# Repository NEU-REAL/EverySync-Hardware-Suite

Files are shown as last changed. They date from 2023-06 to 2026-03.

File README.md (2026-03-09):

# EverySync --  An Open Hardware Time Syncronization Sensor Suite
**EverySync** is An Open Hardware Time Syncronization Sensor Suite For Every Casual Sensor In Field Of SLAM.
- Our project provides a complete, open-source hardware, firmware and software bundle to perform `Hardware Time Synchronization ` of multiple sensors in SLAM system.
  
<div align=center>
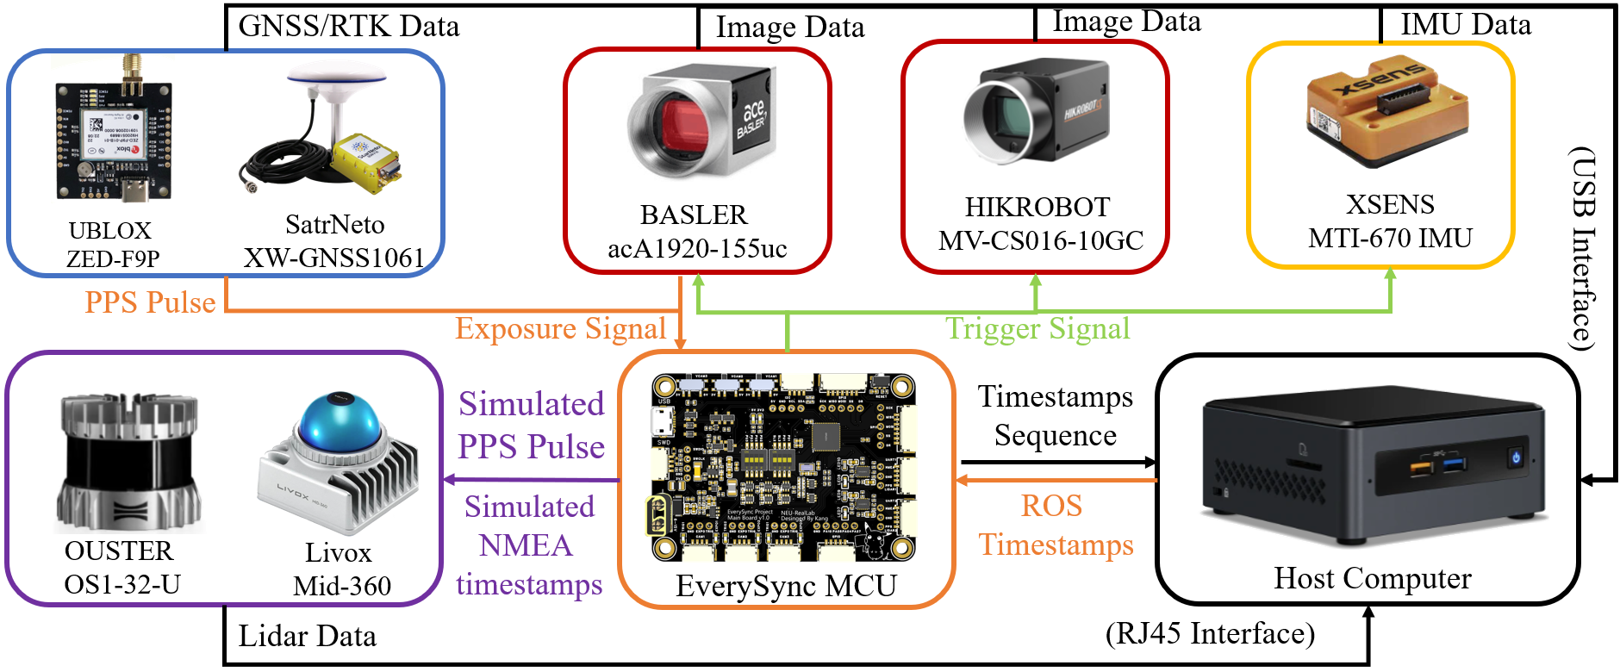
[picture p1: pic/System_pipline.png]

</div>

Entry of This Project:

* [EverySync -- HardwareSuite](https://github.com/NEU-REAL/EverySync-Hardware-Suite) Open source Hardware Suite of EverySync.
* [EverySync -- PCB and Examples](https://github.com/NEU-REAL/EverySync-Hardware-Suite/tree/master/EverySync_PCB) Released. Both [Altium Designer](https://github.com/NEU-REAL/EverySync-Hardware-Suite/tree/master/EverySync_PCB/PCB/EverySync_AD) and [LCEDA](https://oshwhub.com/theconquerk/01-mcu-schdoc_copy) versions are provided, make sure the project is easy to reproduce. And we also provide some examples for developers to create their own hardware suites.

<div align=center>
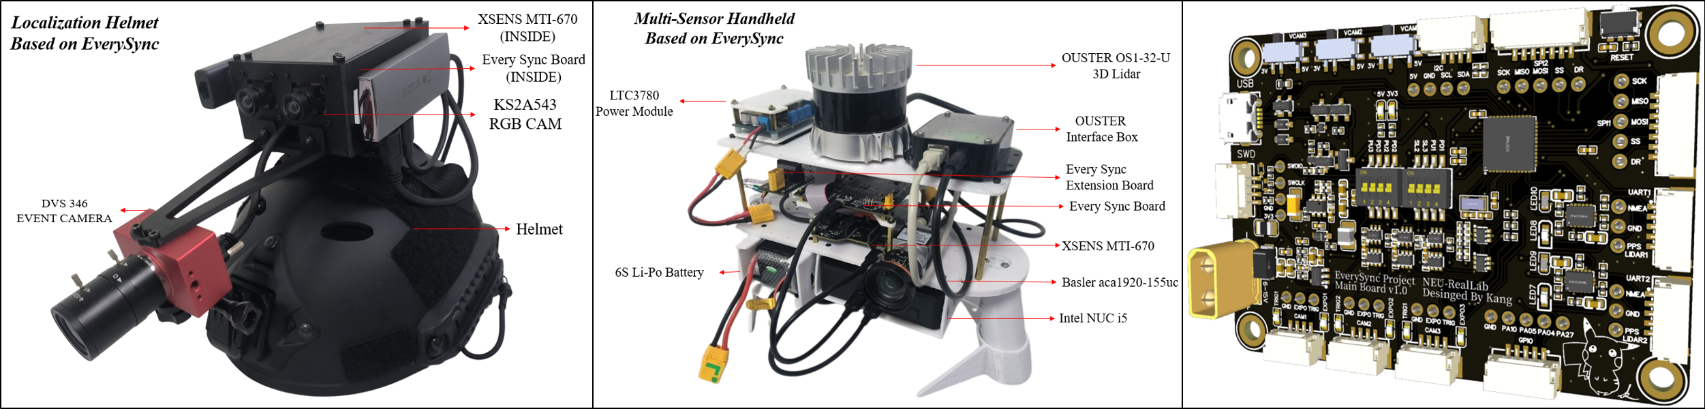
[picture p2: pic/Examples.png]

</div>

## News
- **May 26, 2022** Finish first version named RealVIS v1.0 .
- **May  8, 2023** Support at least 3 kinds of Lidar.
- **April  2, 2024** Open-source. Submit to IROS2024. Preprint is comming soon.
- **June  30, 2024** Accepted by IROS2024. 
- **December 26, 2024** Proceding of IROS2024 is released.
- **January  13, 2025** Project is totally open source. ⭐Happy New Year⭐. 

## Supported drivers
### Camera 
* [Basler](https://github.com/NEU-REAL/EverySync-Hardware-Suite/tree/master/src/driver/pylon-ros-camera) tested with acA1920-155uc
* [HikVision](https://github.com/NEU-REAL/EverySync-Hardware-Suite/tree/master/src/driver/HIKROBOT-MVS-CAMERA-ROS) tested with HikVision MV-CA023-10UC
#### Camera Support From VersaVIS
* [MatrixVision](https://github.com/ethz-asl/bluefox2/tree/devel/versavis) tested with Bluefox 2 MLC200WG, needs adaption for new format
* [PointGrey/Flir](https://github.com/ethz-asl/flir_camera_driver/tree/devel/versavis) tested with Chameleon 3, Blackfly S
* [CamBoard](https://github.com/ethz-asl/pico_flexx_driver/tree/devel/versavis) tested with CamBoard pico monstar

### TriggeralbeIMU
* [Xsens](https://github.com/NEU-REAL/EverySync-Hardware-Suite/tree/master/src/driver/xsens_ros) Support Xsens MTi-100 Series & Xsens MTi-600 Series.Tested with Xsens MTi-300,MTi-630,MTi-670-DK.

### IMU Support From VersaVIS
* [ADIS](https://github.com/NEU-REAL/EverySync-Hardware-Suite/tree/master/src/every_sync/every_sync/src) Originally Support ADIS16448 from VersaVIS

### Lidar
* [Ouster](https://github.com/NEU-REAL/EverySync-Hardware-Suite/tree/master/src/driver/pylon-ros-camera) tested with Ouster-OS1-32
* [Robosense](https://github.com/NEU-REAL/EverySync-Hardware-Suite/tree/master/src/driver/HIKROBOT-MVS-CAMERA-ROS) tested with Robosense16
* [Livox](https://github.com/NEU-REAL/EverySync-Hardware-Suite/tree/master/src/driver/HIKROBOT-MVS-CAMERA-ROS) tested with Livox Mid-40 , Mid-70 , Mid-360

### GNSS/GPS
* [Ublox](https://github.com/NEU-REAL/EverySync-Hardware-Suite/tree/master/src/driver/ublox_driver) tested with Ublox ZED-F9P

## Citing

```
@inproceedings{wu2024everysync,
  title={EverySync: An Open Hardware Time Synchronization Sensor Suite for Common Sensors in SLAM},
  author={Wu, Xuankang and Sun, Haoxiang and Wu, Rongguang and Fang, Zheng},
  booktitle={2024 IEEE/RSJ International Conference on Intelligent Robots and Systems (IROS)},
  pages={12587--12593},
  year={2024},
  organization={IEEE}
}
```

## Install

### Clone and build
```
cd catkin_ws/src
git clone https://github.com/NEU-REAL/EverySync-Hardware-Suite.git
catkin_make
```

```
cd everysync/firmware
./setup.sh
```

### Setup udev rule
Add yourself to `dialout` group
```
sudo adduser <username> dialout
```

Copy udev rule file to your system:
```
sudo cp firmware/98-versa-vis.rules /etc/udev/rules.d/98-versa-vis.rules
```
Afterwards, use the following commands to reload the rules
```
sudo udevadm control --reload-rules
sudo udevadm trigger
sudo ldconfig
```
Note: You might have to reboot your computer for this to take effect. You can check by see whether a `/dev/versavis` is available and pointing to the correct device.

### Configure
Adapt the [configuration file](https://github.com/ethz-asl/versavis/blob/master/firmware/libraries/versavis/src/versavis_configuration.h) to your setup needs. Also check the [datasheet](https://drive.google.com/file/d/11QCjc5PVuMU9bAr8Kjvqz2pqVIhoMbHA/view?ts=5dc98776) for how to configure the hardware switches.

### Flash firmware on the VersaVIS board
* Install the arduino IDE from [here](https://www.arduino.cc/en/Main/OldSoftwareReleases#previous). Use version 1.8.2!
    - Note that a small modification of the install script (`install.sh`) might be required. In particular you may need to change the line `RESOURCE_NAME=cc.arduino.arduinoide` to `RESOURCE_NAME=arduino-arduinoide` as per the issue [here](https://github.com/arduino/Arduino/issues/6116#issuecomment-290012812).
* Open `firmware/everysync/everysync.ino` in the IDE
* Go to `File -> Preferences`
* Change Sketchbook location to `versavis/firmware/`
* Install board support:
    - For EverySync: [Check here](https://github.com/ethz-asl/versavis_hw/)
* Set `Tools -> Port -> tty/ACM0 (Arduino Zero)`, and `Tools -> Board -> VersaVIS`.
* Compile using the *Verify* menu option
* Flash using the *Upload* menu option

## Usage
* Adapt `everysync/launch/pps_test.launch` to your needs.
* Run with
```
roslaunch everysync pps_test.launch
```
* Wait for successfull initialization.
* Or initialization by publish rostopic.
```
./init_cam.sh
```

## Acknowledgements
**There are several important works which support this project:**
- [VersaVIS](https://github.com/ethz-asl/versavis): An Open Versatile Multi-Camera Visual-Inertial Sensor Suite
- [Versavis-Hw](https://github.com/ethz-asl/versavis_hw): VersaVIS Board package for arduino IDE.

## Licence
The source code is released under [GPLv3](https://www.gnu.org/licenses/) license.

## Maintenance
We are still working on extending the proposed system and improving code reliability.

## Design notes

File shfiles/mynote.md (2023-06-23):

->启动 
setserial /dev/ttyUSB0 low_latency
roslaunch versavis real_start.launch
->rosserial单独连接触发板 
->rostopic复位触发板 
$ rosrun rosserial_arduino serial_node.py _port:=/dev/versavis _baud:=250000
$ rostopic pub /versavis/reset std_msgs/Bool false --once

Attention:初次上电后需要复位触发板 复位后立即启动real_start.launch
->python 录制数据包
$ rosbag record -O ms_test.bag  /versavis/cam1/image_raw /versavis/cam2/image_raw /versavis/cam1/image_time /versavis/cam2/image_time /versavis/xsens_imu/image_time /versavis/xsens_imu/data

->python 画图评估脚本

-->ros到达时间给定时间戳计算
$ python real_show_timings.py --input_rosbag /home/kang/realvisWs/bag_file/ms_test.bag --topic /versavis/cam2/image_time

-->延迟时间计算：此延迟是积分时间结束与 ROS 驱动程序给出的时间戳之间的时间。 通常，这对应于传感器的最高帧速率（也可能受接口带宽的影响）。
$ python real_calculate_img_delay.py --input_rosbag /home/kang/realvisWs/bag_file/ms_test.bag --cam0 /versavis/cam1/image_raw --cam1 /versavis/cam2/image_raw
->录制轨迹地图数据包
rosbag record -O realvis_track_5_25_1.bag /versavis/xsens_imu/data /versavis/cam1/image_raw /hikrobot_camera/rgb /imu/data /mynteye/left_rect/image_rect /mynteye/imu/data_raw

截取		
		secs:  1653313555
		nsecs:  1081023

		secs:  1653313759
		nsecs:  751216031

rosbag filter realvis_track_5_23_0.bag cut_realvis_track.bag "t.to_sec() >= 1653313555.1081023 and t.to_sec() <= 1653313759.751216031"

rosbag record -O mynt_track.bag /mynteye/left_rect/image_rect /mynteye/imu/data_raw

rosbag record -O orb_track_5_25_1.bag /versavis/xsens_imu/data /versavis/cam1/image_raw /hikrobot_camera/rgb /imu/data /mynteye/left_rect/image_rect /mynteye/imu/data_raw

#轨迹绘制
1. 数据转换
evo_traj euroc data.csv --save_as_tum
2. 轨迹绘制
evo_traj tum vins_result_no_loop.csv -p --plot_mode=xy
evo_traj tum vins_result_loop.csv -p --plot_mode=xy
evo_traj tum 5_25_1mynt/vins_result_no_loop.csv 5_25_1realvis_sync/vins_result_no_loop.csv -p --plot_mode=xy
evo_traj tum 5_25_1mynt/vins_result_no_loop.csv 5_25_1realvis_sync/vins_result_no_loop.csv -p --plot_mode=xy

xsens mti ros driver attention!!!
The published topics do not reach the expected data output rate (e.g. 400 Hz).
We have noticed that the ROS node can cause a high CPU load, leading to lower data output rates. This issue has been fixed in ROS nodes available in MTSS2019.3.2 and later. We recommend migrating to the latest version.

If you have connected the MTi via a USB interface, we recommend enabling the low latency mode using setserial:

Install setserial if not already installed
Enable low latency mode:

$ setserial [/path/to/xsens/port] low_latency
setserial /dev/ttyUSB0 low_latency

Check the output rate of the published topics, e.g:

$ rostopic hz imu/data

imu timestamp

		nsecs:  462945000
		nsecs:  472942000
		nsecs:  482940000
		nsecs:  492938000
均匀
bag1
image timestamp 1
		nsecs:  101840000
		nsecs:  149825000
		nsecs:  197811000

image timestamp 2
		nsecs:  149967000
		nsecs:  197953000
		nsecs:  245938000

		secs:  1682585875
		nsecs:  830734968
		secs:  303067339
		nsecs:  880780000

		secs:  1682586175
		nsecs:  451132059
		secs:  3358979009
		nsecs:  749697000

43.183
		secs:  1686309290
		nsecs:  448941000

		secs:  1686309290
		nsecs:  505958519

57,017,519

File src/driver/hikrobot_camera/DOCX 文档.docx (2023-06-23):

HIKROBOT_VISION

管脚 信号

I/O 信号源 说明

1

DC_PWR

相机电源

2

OPTO_IN

Line 0+

光耦隔离输入

3

GPIO

Line 2+

可配置输入或输出

4

OPTO_OUT

Line 1+

光耦隔离输出

5

OPTO_GND

Line 0/1-

光耦隔离信号地

6

GND

Line 2-

相机电源地

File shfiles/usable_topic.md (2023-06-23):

/REAL_camera_manager/bond
/basler_camera_node/img_numbered
/clicked_point
/diagnostics
/hikrobot_camera/camera_info
/hikrobot_camera/img_numbered
/hikrobot_camera/rgb
/hikrobot_camera/rgb/compressed
/hikrobot_camera/rgb/compressed/parameter_descriptions
/hikrobot_camera/rgb/compressed/parameter_updates
/hikrobot_camera/rgb/compressedDepth
/hikrobot_camera/rgb/compressedDepth/parameter_descriptions
/hikrobot_camera/rgb/compressedDepth/parameter_updates
/hikrobot_camera/rgb/theora
/hikrobot_camera/rgb/theora/parameter_descriptions
/hikrobot_camera/rgb/theora/parameter_updates
/imu/data
/imu_data_str
/initialpose
/move_base_simple/goal
/pylon_camera_node/camera_info
/pylon_camera_node/currentParams
/pylon_camera_node/grab_images_raw/cancel
/pylon_camera_node/grab_images_raw/feedback
/pylon_camera_node/grab_images_raw/goal
/pylon_camera_node/grab_images_raw/result
/pylon_camera_node/grab_images_raw/status
/pylon_camera_node/image_raw
/pylon_camera_node/image_raw/compressed
/pylon_camera_node/image_raw/compressed/parameter_descriptions
/pylon_camera_node/image_raw/compressed/parameter_updates
/pylon_camera_node/image_raw/compressedDepth
/pylon_camera_node/image_raw/compressedDepth/parameter_descriptions
/pylon_camera_node/image_raw/compressedDepth/parameter_updates
/pylon_camera_node/image_raw/theora
/pylon_camera_node/image_raw/theora/parameter_descriptions
/pylon_camera_node/image_raw/theora/parameter_updates
/pylon_camera_node/status
/rosout
/rosout_agg
/tf
/tf_static
/time_reference
/versavis/cam1/image_raw
/versavis/cam1/image_raw/compressed
/versavis/cam1/image_raw/compressed/parameter_descriptions
/versavis/cam1/image_raw/compressed/parameter_updates
/versavis/cam1/image_raw/compressedDepth
/versavis/cam1/image_raw/compressedDepth/parameter_descriptions
/versavis/cam1/image_raw/compressedDepth/parameter_updates
/versavis/cam1/image_raw/theora
/versavis/cam1/image_raw/theora/parameter_descriptions
/versavis/cam1/image_raw/theora/parameter_updates
/versavis/cam1/image_time
/versavis/cam1/init
/versavis/cam2/image_raw
/versavis/cam2/image_raw/compressed
/versavis/cam2/image_raw/compressed/parameter_descriptions
/versavis/cam2/image_raw/compressed/parameter_updates
/versavis/cam2/image_raw/compressedDepth
/versavis/cam2/image_raw/compressedDepth/parameter_descriptions
/versavis/cam2/image_raw/compressedDepth/parameter_updates
/versavis/cam2/image_raw/theora
/versavis/cam2/image_raw/theora/parameter_descriptions
/versavis/cam2/image_raw/theora/parameter_updates
/versavis/cam2/image_time
/versavis/cam2/init
/versavis/reset
/versavis/xsens_imu/data
/versavis/xsens_imu/image_time
/versavis/xsens_imu/init
/xsens/imu_numbered

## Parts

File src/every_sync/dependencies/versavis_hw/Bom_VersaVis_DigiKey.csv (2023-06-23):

Manufacturer Part Number | Manufacturer | Digi-Key Part Number | Reference Designator | Packaging | Part Status | Quantity | Unit Price | Extended Price | Quantity Available | Mfg Std Lead Time | Description
CRCW060350R0FKEA | Vishay Dale | 541-3318-1-ND | R102 | Cut Tape (CT) | Active | 1 | 0,09000 | 0,09 € | 0 | 52 Weeks | RES SMD 50 OHM 1% 1/10W 0603
C0603C472K1GEC7867 | KEMET | 399-14206-1-ND | C101, C201, C202 | Cut Tape (CT) | Active | 3 | 0,26000 | 0,78 € | 3719 | 24 Weeks | CAP CER 4700PF 100V C0G/NP0 0603
CL21B105KAFNNNE | Samsung Electro-Mechanics | 1276-1066-1-ND | C203, C204, C205 | Cut Tape (CT) | Active | 3 | 0,09000 | 0,27 € | 15526 | 28 Weeks | CAP CER 1UF 25V X7R 0805
C0603C104J4RACTU | KEMET | 399-1097-1-ND | C207, C401, C501, C601_1, C601_2, C601_3, C602_1, C602_2, C602_3, C603_1, C603_2, C603_3, C304, C305, C307, C309 | Cut Tape (CT) | Active | 16 | 0,08500 | 1,36 € | 1900438 | 23 Weeks | CAP CER 0.1UF 16V X7R 0603
04023A200JAT2A | AVX Corporation | 478-11740-1-ND | C301, C302 | Cut Tape (CT) | Active | 2 | 0,26000 | 0,52 € | 4922 | 16 Weeks | CAP CER 20PF 25V C0G/NP0 0402
GRM188C81C475KE11D | Murata Electronics | 490-13362-1-ND | C303, C306, C308 | Cut Tape (CT) | Active | 3 | 0,32000 | 0,96 € | 0 | 23 Weeks | CAP CER 4.7UF 16V X6S 0603
GRM21BC71E106KE11L | Murata Electronics | 490-10496-1-ND | C402, C403, C206 | Cut Tape (CT) | Active | 3 | 0,51000 | 1,53 € | 66009 | 23 Weeks | CAP CER 10UF 25V X7S 0805
0430450400 | Molex | WM1814-ND | CAM101, CAM102, CAM103 | Tray | Active | 3 | 1,20000 | 3,60 € | 26834 | 6 Weeks | CONN HEADER R/A 4POS 3MM
PRTR5V0U2X,215 | Nexperia USA Inc. | 1727-3884-1-ND | D101 | Cut Tape (CT) | Active | 1 | 0,41000 | 0,41 € | 531 | 8 Weeks | TVS DIODE 5.5V SOT143B
B0540W-7-F | Diodes Incorporated | B0540W-FDICT-ND | D102, D201, D203 | Cut Tape (CT) | Active | 3 | 0,27000 | 0,81 € | 0 | 24 Weeks | DIODE SCHOTTKY 40V 500MA SOD123
LG R971-KN-1 | OSRAM Opto Semiconductors Inc. | 475-1410-1-ND | D202, D204, D504, D505, D506 | Cut Tape (CT) | Active | 5 | 0,22000 | 1,10 € | 283121 | 12 Weeks | LED GREEN DIFFUSED 0805 SMD
LO R976-PS-1 | OSRAM Opto Semiconductors Inc. | 475-2488-2-ND | D501, D502, D503 | Tape & Reel (TR) | Active | 3 | 0,00000 | 0,00 € | 4307 | 16 Weeks | LED ORANGE DIFFUSED 0805 SMD
MF-MSMF050-2 | Bourns Inc. | MF-MSMF050-2CT-ND | F201, F202 | Cut Tape (CT) | Active | 2 | 0,27000 | 0,54 € | 11326 | 20 Weeks | PTC RESET FUSE 15V 500MA 1812
DF13A-4P-1.25H(51) | Hirose Electric Co Ltd | H125779CT-ND | I101 | Cut Tape (CT) | Active | 1 | 0,79000 | 0,79 € | 52 | 26 Weeks | CONN HEADER SMD R/A 4POS 1.25MM
0475890001 | Molex | WM17143CT-ND | J101 | Cut Tape (CT) | Active | 1 | 0,66000 | 0,66 € | 16302 | 12 Weeks | CONN RCPT MICRO USB AB 5P SMD RA
BLM18PG471SN1D | Murata Electronics | 490-5223-1-ND | L201 | Cut Tape (CT) | Active | 1 | 0,09000 | 0,09 € | 0 | 15 Weeks | FERRITE BEAD 470 OHM 0603 1LN
BLM21BD152SN1D | Murata Electronics | 490-1048-1-ND | L301 | Cut Tape (CT) | Active | 1 | 0,18000 | 0,18 € | 13310 | 16 Weeks | FERRITE BEAD 1.5 KOHM 0805 1LN
2N7002DW-7-F | Diodes Incorporated | 2N7002DW-FDICT-ND | Q201 | Cut Tape (CT) | Active | 1 | 0,30000 | 0,30 € | 0 | 45 Weeks | MOSFET 2N-CH 60V 0.23A SOT-363
ERJ-3GEYJ105V | Panasonic Electronic Components | P1.0MGCT-ND | R101 | Cut Tape (CT) | Active | 1 | 0,09000 | 0,09 € | 263582 | 29 Weeks | RES SMD 1M OHM 5% 1/10W 0603
RT0603FRE0710KL | Yageo | YAG2321CT-ND | R201, R205, R302, R303, R403, R404, R407, R408, R601_1, R601_2, R601_3, R602_1, R602_2, R602_3, R603_1, R603_2, R603_3 | Cut Tape (CT) | Active | 17 | 0,04800 | 0,81 € | 129389 | 20 Weeks | RES SMD 10K OHM 1% 1/10W 0603
CRCW0603270RFKEA | Vishay Dale | 541-270HCT-ND | R202, R405, R406, R501, R502, R503, R504, R505, R506 | Cut Tape (CT) | Active | 9 | 0,09000 | 0,81 € | 0 | 52 Weeks | RES SMD 270 OHM 1% 1/10W 0603
RT0603FRE07100KL | Yageo | YAG2319CT-ND | R203, R207, R208 | Cut Tape (CT) | Active | 3 | 0,09000 | 0,27 € | 84 | 20 Weeks | RES SMD 100K OHM 1% 1/10W 0603
CRCW0603470RFKEAC | Vishay Dale | 541-4038-1-ND | R204, R206, R304, R306 | Cut Tape (CT) | Active | 4 | 0,09000 | 0,36 € | 37544 | 22 Weeks | RES 470 OHM 1% 1/10W 0603
CPF0603B39RE1 | TE Connectivity Passive Product | A103095CT-ND | R305 | Cut Tape (CT) | Active | 1 | 0,50000 | 0,50 € | 1795 | 21 Weeks | RES SMD 39 OHM 0.1% 1/16W 0603
CRCW06032K20FKEAC | Vishay Dale | 541-4022-1-ND | R401, R402 | Cut Tape (CT) | Active | 2 | 0,09000 | 0,18 € | 4900 | 22 Weeks | RES 2.2K OHM 1% 1/10W 0603
LB Q39G-L2OO-35-1 | OSRAM Opto Semiconductors Inc. | 475-2816-1-ND | RX401, TX401 | Cut Tape (CT) | Active | 2 | 0,30000 | 0,60 € | 34058 | 12 Weeks | LED BLUE DIFFUSED 0603 SMD
CJS-1201TA | Nidec Copal Electronics | 563-1023-1-ND | S601_1, S601_2, S601_3 | Cut Tape (CT) | Active | 3 | 0,87000 | 2,61 € | 17139 | 11 Weeks | SWITCH SLIDE SPDT 100MA 6V
DF13A-7P-1.25H(76) | Hirose Electric Co Ltd | H126444-ND | SPI101, SPI102, X102 | Tube | Active | 3 | 0,82000 | 2,46 € | 97 | 26 Weeks | CONN HEADER SMD R/A 7POS 1.25MM
KMR631NG ULC LFS | C&K | CKN10685CT-ND | SW301 | Cut Tape (CT) | Active | 1 | 0,33000 | 0,33 € | 0 | 18 Weeks | SWITCH TACTILE SPST-NO 50MA 32V
219-8LPSTRF | CTS Electrocomponents | CT3120CT-ND | SW501 | Cut Tape (CT) | Active | 1 | 0,95000 | 0,95 € | 212 | 12 Weeks | SWITCH SLIDE DIP SPST 100MA 20V
DMP2065UFDB-7 | Diodes Incorporated | DMP2065UFDB-7DICT-ND | T201, T202 | Cut Tape (CT) | Active | 2 | 0,43000 | 0,86 € | 22 | 40 Weeks | MOSFET 2 P-CH 20V 4.5A DFN2020-6
LD1117S33TR | STMicroelectronics | 497-1242-1-ND | U201 | Cut Tape (CT) | Active | 1 | 0,39000 | 0,39 € | 16450 | 26 Weeks | IC REG LINEAR 3.3V 800MA SOT223
LD1117S50TR | STMicroelectronics | 497-6447-1-ND | U202 | Cut Tape (CT) | Active | 1 | 0,39000 | 0,39 € | 8373 | 26 Weeks | IC REG LINEAR 5V 800MA SOT223
SN74LV123ARGYR | Texas Instruments | 296-13931-1-ND | U401 | Cut Tape (CT) | Active | 1 | 0,52000 | 0,52 € | 15329 | 12 Weeks | IC MULTIVIBRATOR 13NS 16VQFN
NC7NZ17K8X | ON Semiconductor | NC7NZ17K8XCT-ND | U501 | Cut Tape (CT) | Active | 1 | 0,47000 | 0,47 € | 31005 | 37 Weeks | IC BUFFER NON-INVERT 5.5V US8
SN74LVC1T45DPKR | Texas Instruments | 296-30277-1-ND | U601_1, U601_2, U601_3 | Cut Tape (CT) | Active | 3 | 0,50000 | 1,50 € | 3907 | 6 Weeks | IC TRNSLTR BIDIRECTIONAL 6USON
NC7SZ157P6X | ON Semiconductor | NC7SZ157P6XCT-ND | U602_1, U602_2, U602_3 | Cut Tape (CT) | Active | 3 | 0,38000 | 1,14 € | 18995 | 41 Weeks | IC MULTIPLEXER 1 X 2:1 SC88
0436500201 | Molex | WM1865-ND | X101 | Tray | Active | 1 | 1,02000 | 1,02 € | 11487 | 5 Weeks | CONN HEADER R/A 2POS 3MM
DF13A-6P-1.25H(21) | Hirose Electric Co Ltd | H125991CT-ND | X103 | Cut Tape (CT) | Active | 1 | 0,55000 | 0,55 € | 3742 | 26 Weeks | CONN HEADER SMD R/A 6POS 1.25MM
FK135EIHM0.032768-T3 | Fox Electronics | 631-1002-1-ND | XTAL301 | Cut Tape (CT) | Active | 1 | 0,70000 | 0,70 € | 0 | 54 Weeks | CRYSTAL 32.7680KHZ 12.5PF SMD

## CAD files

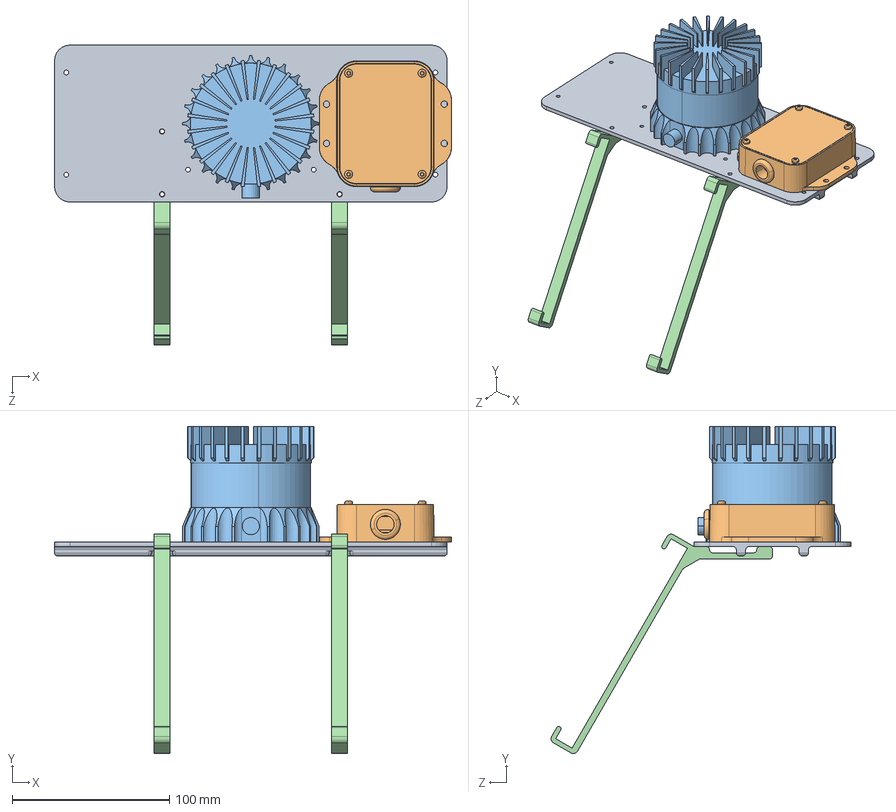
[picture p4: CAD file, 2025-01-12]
EverySync_PCB/Examples/LiDAR_asm.SLDASM
252.7 x 208.3 x 190.9 mm
LiDAR_board
Interface-box
ouster.step
screenhold x 2

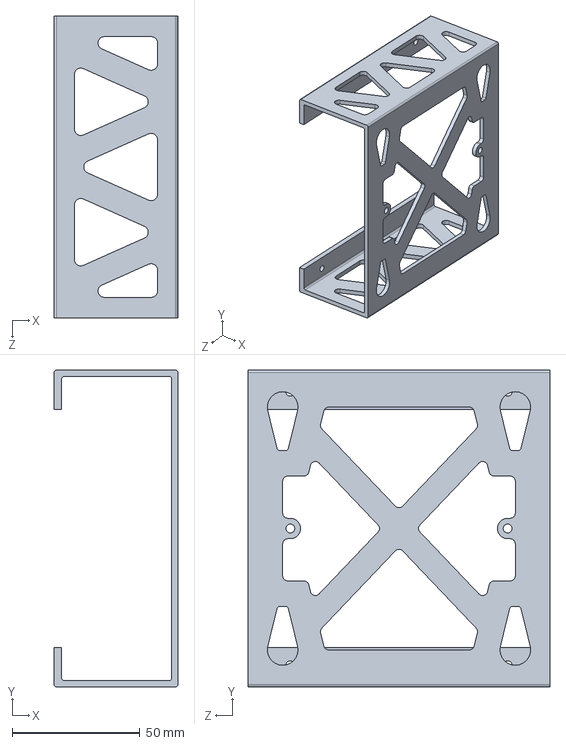
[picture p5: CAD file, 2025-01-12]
EverySync_PCB/Examples/pc_content.SLDPRT
48.5 x 124.0 x 118.0 mm

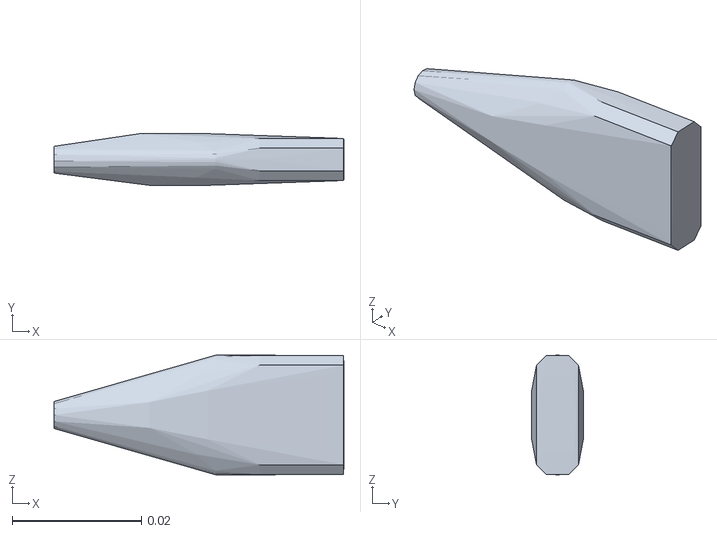
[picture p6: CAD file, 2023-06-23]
src/driver/realsense-ros/realsense2_description/meshes/plug_collision.stl
0.0448 x 0.008 x 0.0185

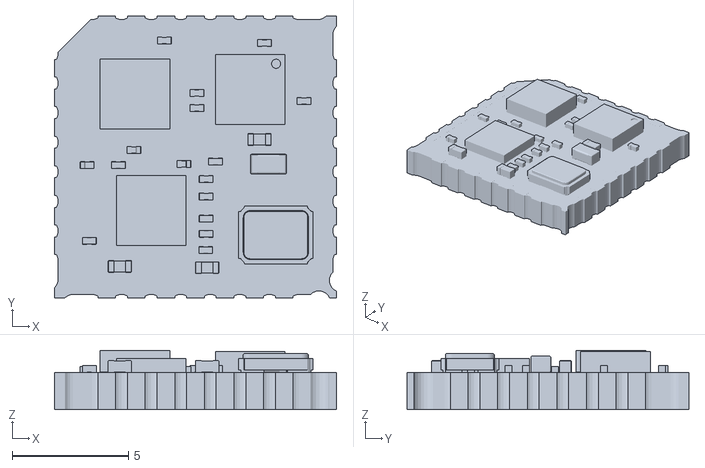
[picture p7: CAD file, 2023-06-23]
src/driver/xsens_ros/src/xsens_ros_mti_driver/urdf/MTi_1.stl
12.1 x 12.1 x 2.56

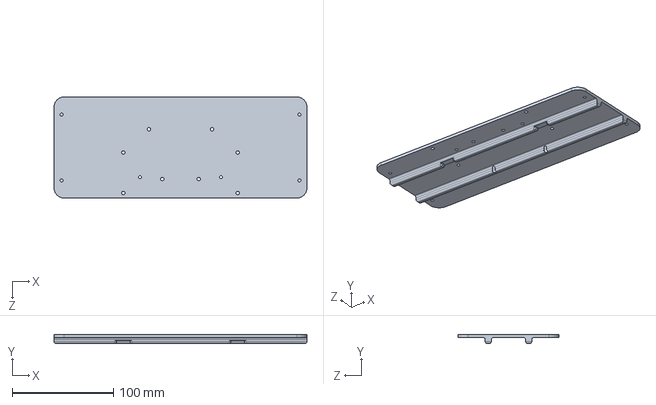
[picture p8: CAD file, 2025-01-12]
EverySync_PCB/Examples/LiDAR_board.SLDPRT
250.0 x 9.00 x 100.0 mm

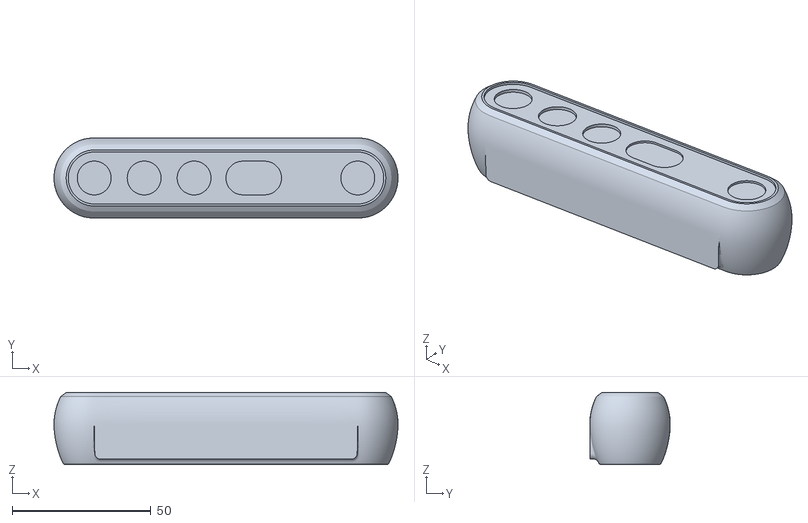
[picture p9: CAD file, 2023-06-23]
src/driver/realsense-ros/realsense2_description/meshes/d455.stl
124.0 x 29.0 x 26.0

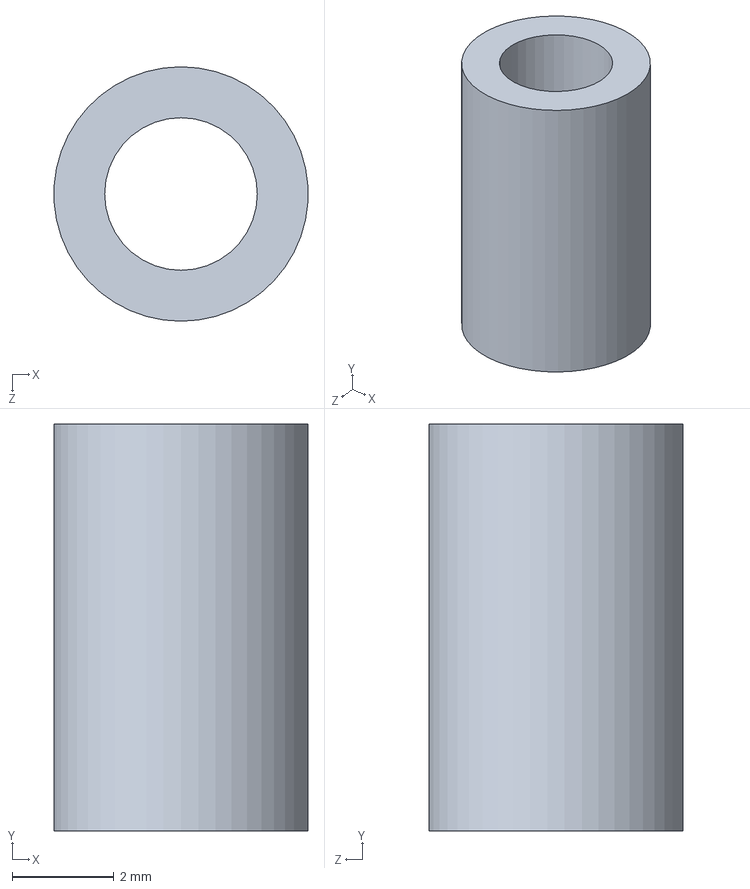
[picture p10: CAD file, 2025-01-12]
EverySync_PCB/Examples/柱3×8.SLDPRT
4.99 x 8.00 x 5.00 mm

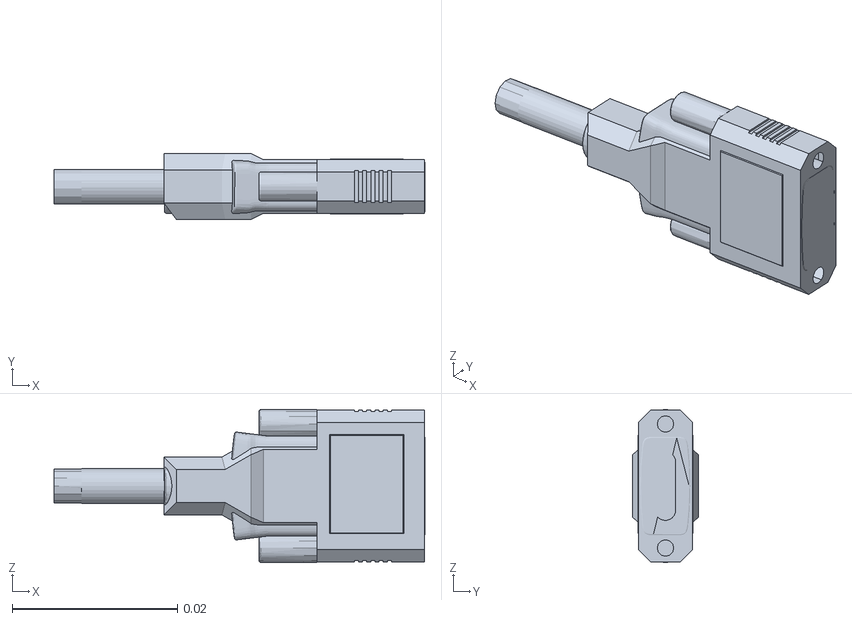
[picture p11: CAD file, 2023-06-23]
src/driver/realsense-ros/realsense2_description/meshes/plug.stl
0.0448 x 0.008 x 0.0185

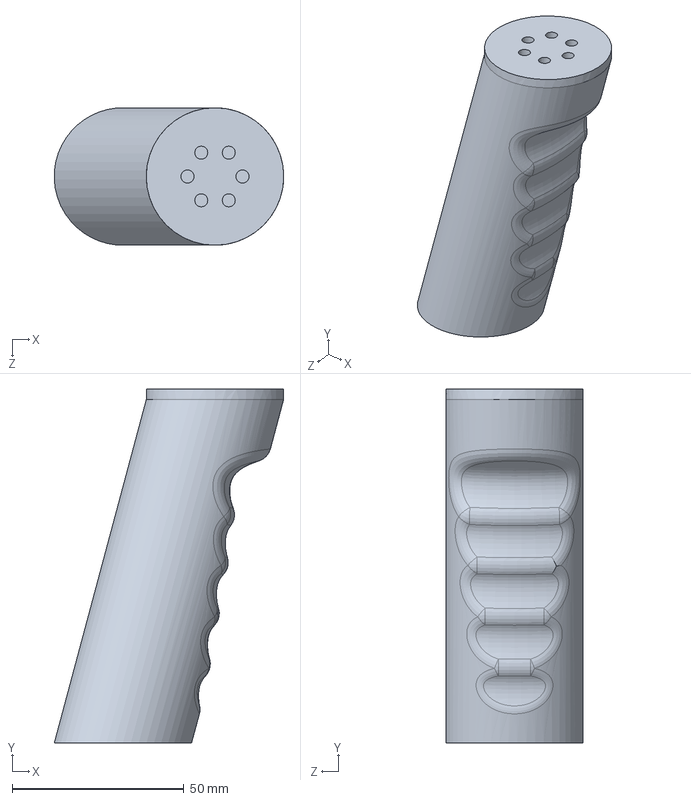
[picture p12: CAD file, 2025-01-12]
EverySync_PCB/Examples/smooth_handle.SLDPRT
66.8 x 103.0 x 40.0 mm

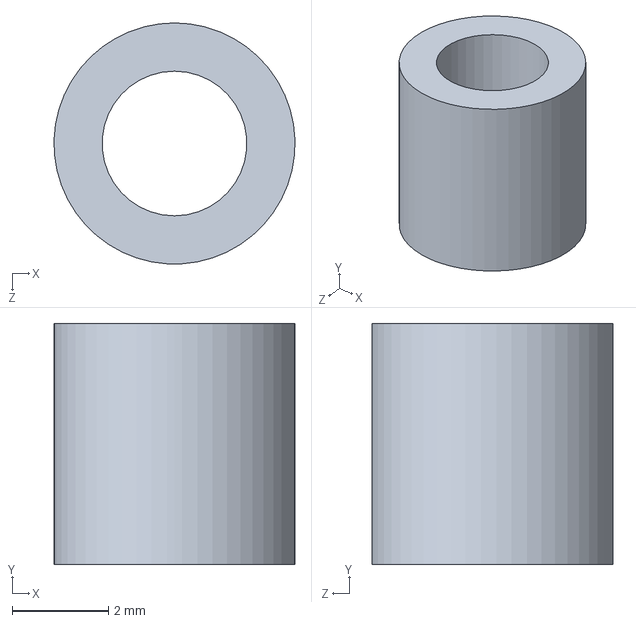
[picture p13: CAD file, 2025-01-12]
EverySync_PCB/Examples/柱3×5.SLDPRT
5.00 x 5.00 x 5.00 mm

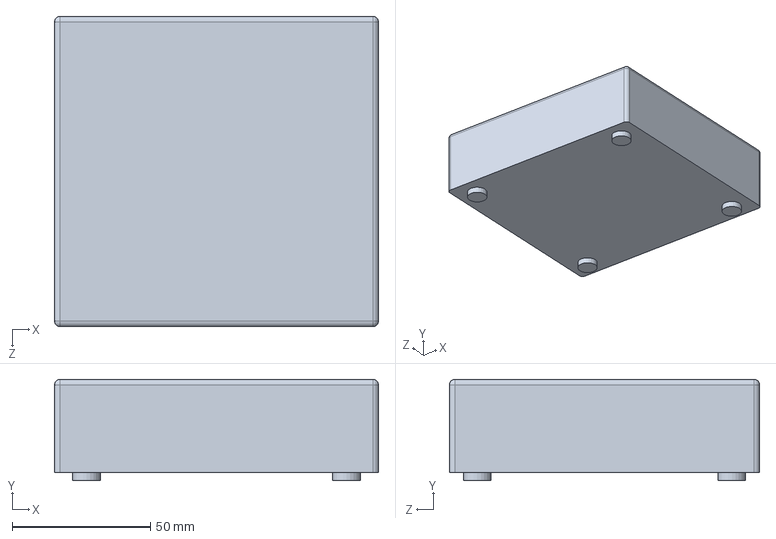
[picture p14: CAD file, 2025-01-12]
EverySync_PCB/Examples/nuc.SLDPRT
117.1 x 36.7 x 112.1 mm

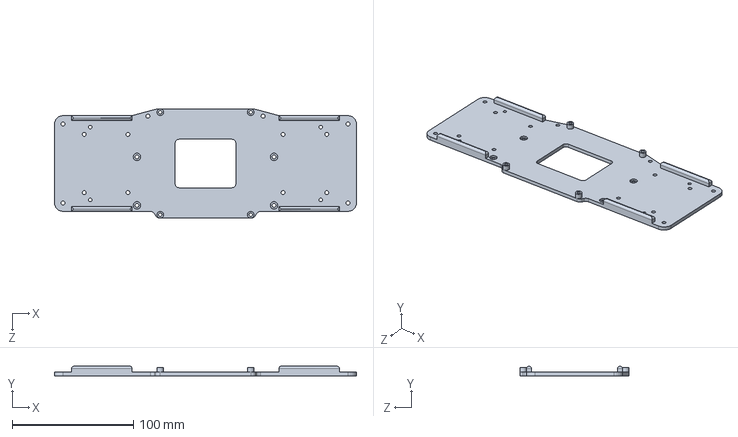
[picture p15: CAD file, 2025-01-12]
EverySync_PCB/Examples/upboard.SLDPRT
249.0 x 8.00 x 90.0 mm

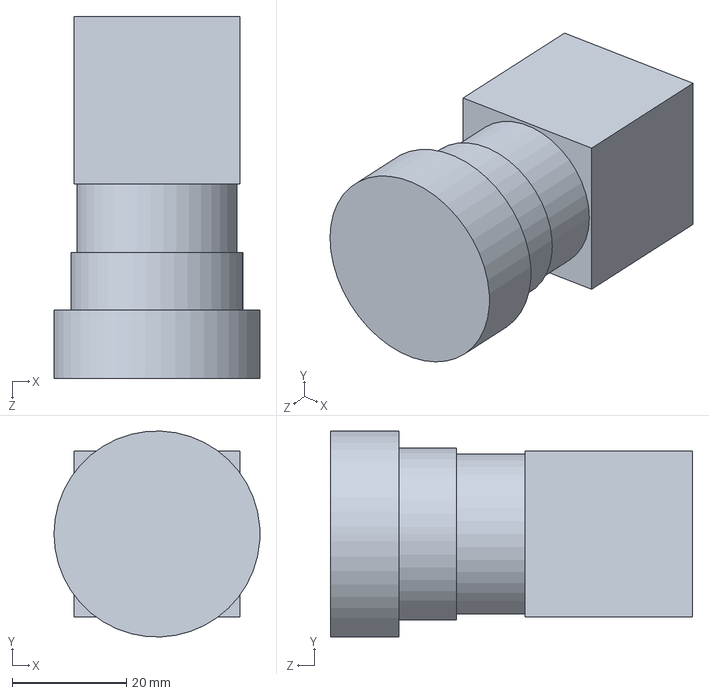
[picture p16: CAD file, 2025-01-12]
EverySync_PCB/Examples/camera.SLDPRT
36.0 x 36.0 x 63.3 mm

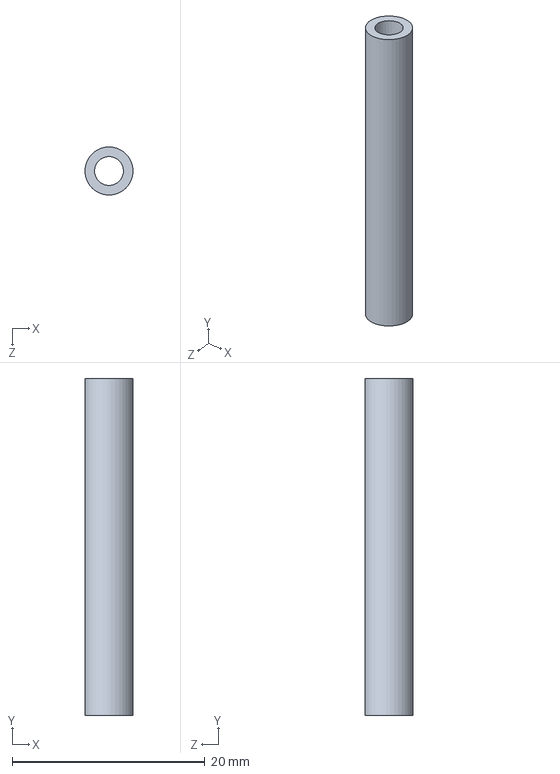
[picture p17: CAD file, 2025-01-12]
EverySync_PCB/Examples/柱3×35.SLDPRT
5.00 x 35.0 x 5.00 mm

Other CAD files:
EverySync_PCB/Examples/0531_battery_cont.SLDPRT
EverySync_PCB/Examples/screenhold.SLDPRT
EverySync_PCB/Examples/ouster.step.SLDPRT
EverySync_PCB/Examples/0531_pc_content.SLDPRT
EverySync_PCB/Examples/3D_sync_ext_board.SLDPRT
EverySync_PCB/Examples/battery6s.SLDPRT
EverySync_PCB/Examples/battery_cont.SLDPRT
EverySync_PCB/Examples/handheld_base.SLDPRT
EverySync_PCB/Examples/support_v0731.SLDPRT
EverySync_PCB/Examples/柱3×70.SLDPRT

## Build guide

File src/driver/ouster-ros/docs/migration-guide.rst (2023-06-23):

.. title:: Ouster-ROS Driver Migration Guide

===================================
Migrating from 20220608 to 20220826
===================================
The ``20220826`` release brought several improvements to the **ouster-ros** driver, however, these
improvements brought also several breaking changes. This guide summarizes these change and how to
mitigate each one.

Launch Files:
=============
The ``ouster.launch`` has been split into three functionally different launch files:
``sensor.launch``, ``replay.launch``, and ``record.launch``. Each of these launch files only accepts
parameters that are relevant to their functional use. For example, the ``sensor_hostname`` argument
is only valid and required when using the ``sensor.launch`` and ``record.launch`` launch files.
The ``metadata`` argument however is no longer required when connecting to the sensor in live mode.
It is still required when using ``record.launch`` and ``replay.launch``. Refer to the `main
documentation <./doc/index.rst>`_ for more details on the different cases of usage.

Topics
======

Topics Renaming
---------------

Rather than having each topic published by **ouster-ros** be prefixed with the name of the ros node
that publishes it, the topic names of all ros nodes that compose the **ouster-ros** driver have been
combined under a single namespace. Thus all topics would appear prefixed by the new namespace.

If a user wishes to maintain the old topic names then they can achieve that by utilizing the
``<remap>`` tag in ros launch files. For example, let's say we want to remap the three topics
published by ``os_cloud_node`` to their old names when connecting to a sensor through the
``sensor.launch`` file. To do so, we need to edit the ``sensor.launch`` file and add the three
following remap tags right before any node is instantiated (i.e. the ``<remap>`` tag defintions
should precede any ``<node>`` tags in the launch file)::

    <remap from="/$(arg ouster_ns)/imu" to="/os_cloud_node/imu"/>
    <remap from="/$(arg ouster_ns)/points" to="/os_cloud_node/points"/>
    <remap from="/$(arg ouster_ns)/points2" to="/os_cloud_node/points2"/>

Same thing needs to happen if we want to remap the topic names that are published by ``img_node``.
This is shown below as well::

    <remap from="/$(arg ouster_ns)/nearir_image" to="/img_node/nearir_image"/>
    <remap from="/$(arg ouster_ns)/range_image" to="/img_node/range_image"/>
    <remap from="/$(arg ouster_ns)/reflec_image" to="/img_node/reflec_image"/>
    <remap from="/$(arg ouster_ns)/signal_image" to="/img_node/signal_image"/>

Topics Dropped
--------------

Additionally, the following two topic have been dropped::

    /os1_node/imu_packets
    /os1_node/lidar_packets

These two topics are a duplicates of the ``/os_node/imu_packets`` and ``/os_node/lidar_packets``,
which both have been renamed to  ``/ouster/imu_packets`` and ``/ouster/lidar_packets`` respectively.
If you rely on these specific topics names in your integration then you could easily follow same
steps described in the `Topics Renaming`_ section.

Services
========
This update brought two additional ros services and changed the name of the only ros service that
existed prior to this release. The service name was ``/os_config`` and when it is invoked it would
retrive the sensor metadata. This service was also combined under the unifed namespace ``ouster``
and was renamed to ``get_metadata`` to match its actual functionality. In case the user wish to
maintain the old name they can achieve so in similar manner that was described in the previous
section. In short edit the launch files and add the following ```<remap>`` tag prior to the 
instantiation of any of the three nodes::

    <remap from="/$(arg ouster_ns)/get_metadata" to="/os_config"/>

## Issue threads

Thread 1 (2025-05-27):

硬件代码烧录

kinggreat24, 2025-05-27:
这个是使用什么烧录器进行代码烧录啊

TheConquerK, 2025-05-28:
用J-Link就可以 烧录流程可以参考这个blog [ATSAMD21g18 Bootloader With J-link Debugger](https://www.instructables.com/ATSAMD21g18-Bootloader-With-J-link-Debugger/) 项目中使用的bootloader为[samd21_sam_ba_versavis.bin](https://github.com/NEU-REAL/EverySync-Hardware-Suite/blob/master/EverySync_PCB/PCB/EverySync_hw/samd21_sam_ba_versavis.bin)

kinggreat24, 2025-06-04:
我将引导文件烧录进去了，但是VersaVIS也已经添加成功，在Arduino中程序也编译成功了，但是就是Arduino找不到对应的COM口。

TheConquerK, 2025-06-09:
请尝试在windows端查看有无COM口下的Arduino设备，并确认连接线为标准usb2.0 4pin齐全的接线

<!-- Failed to upload "image.png" -->

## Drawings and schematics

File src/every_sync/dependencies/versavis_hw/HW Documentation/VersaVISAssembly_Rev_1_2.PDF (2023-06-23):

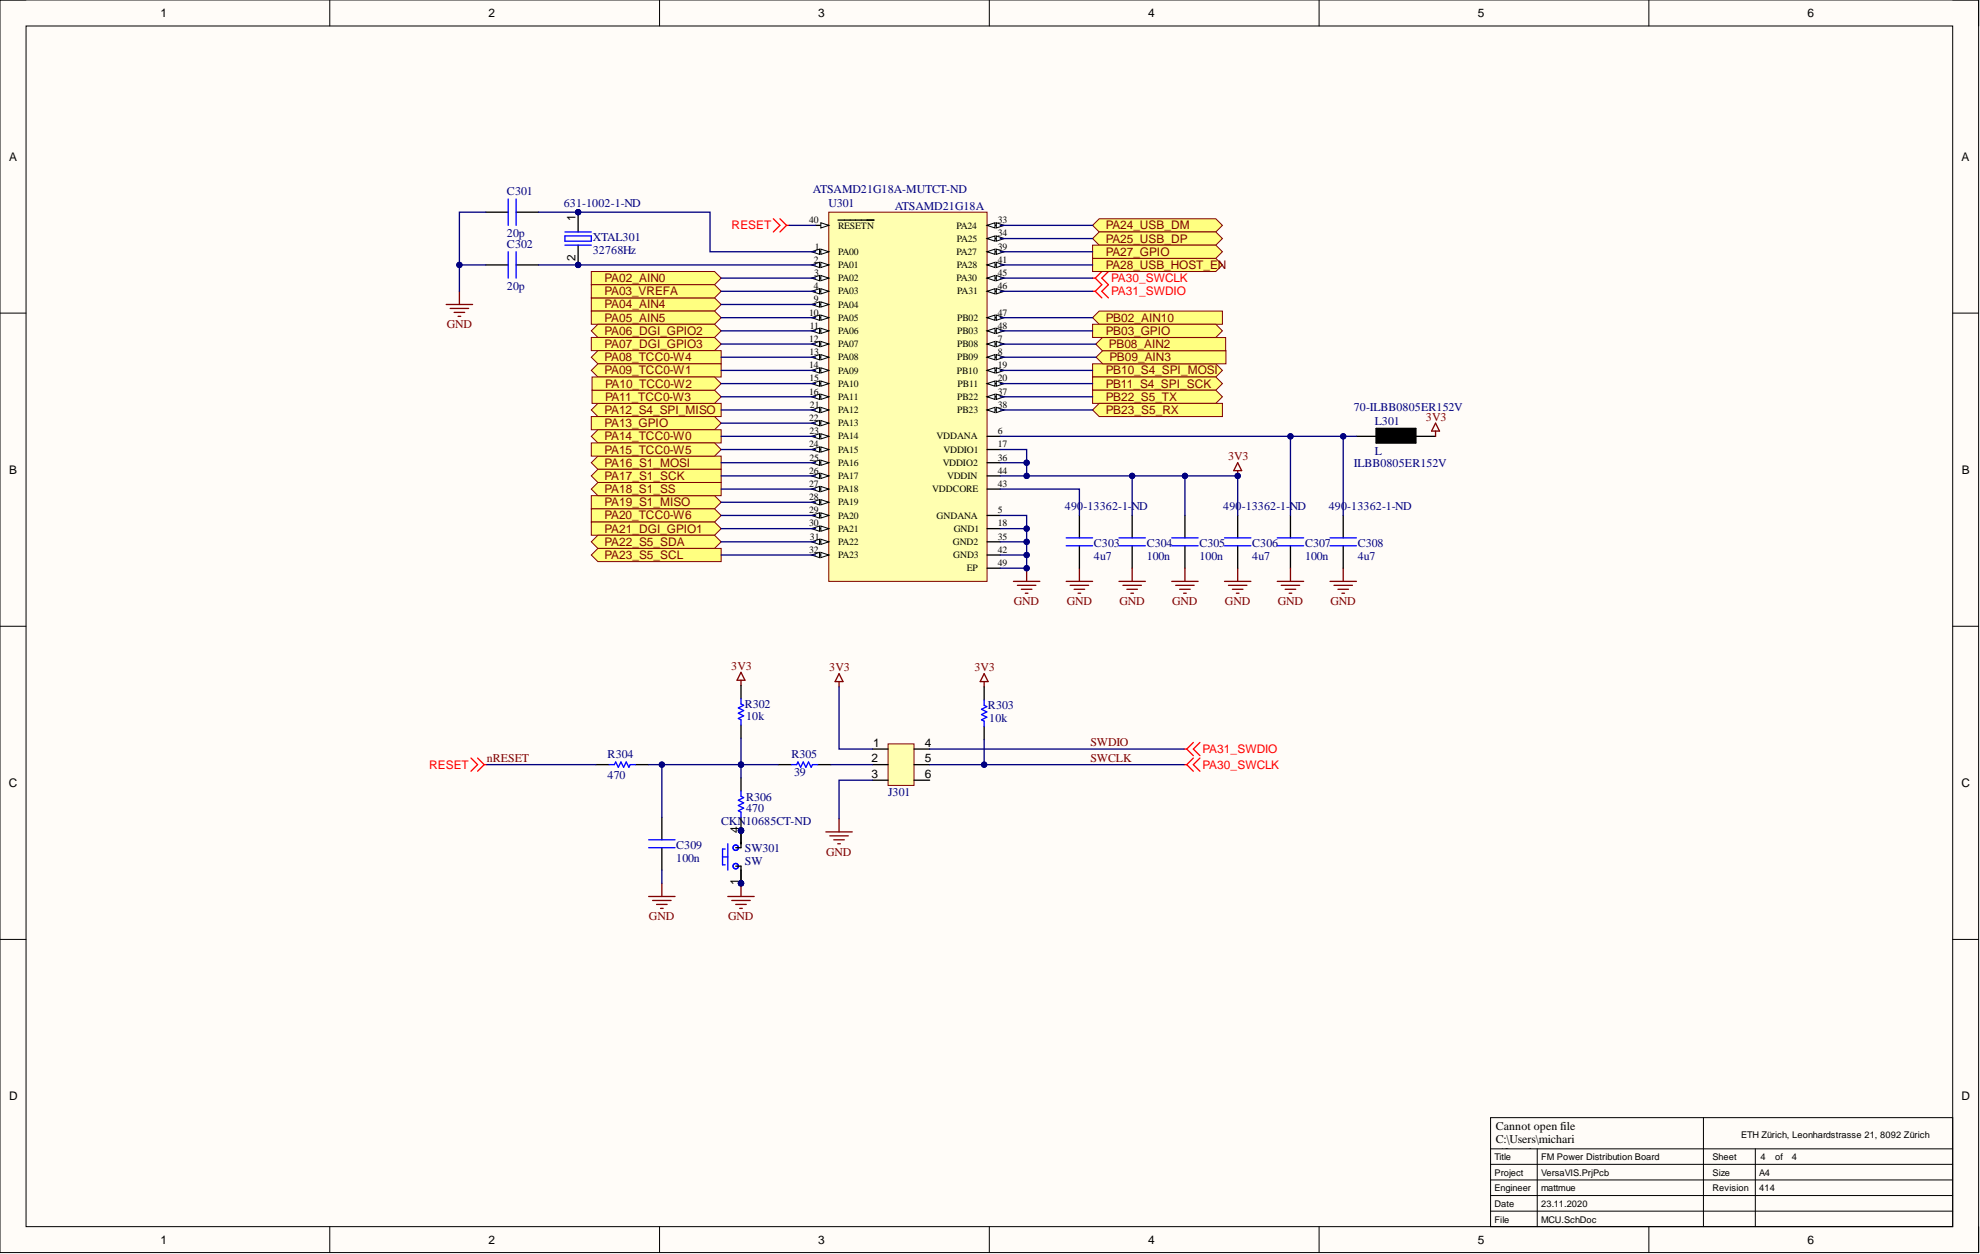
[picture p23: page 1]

Cannot open file C:\Users\michari | ETH Zürich, Leonhardstrasse 21, 8092 Zürich

Title | FM Power Distribution Board | Sheet | 4 of 4

Project | VersaVIS.PrjPcb | Size | A4
Engineer | mattmue | Revision
Date | 23.11.2020

File | MCU.SchDoc

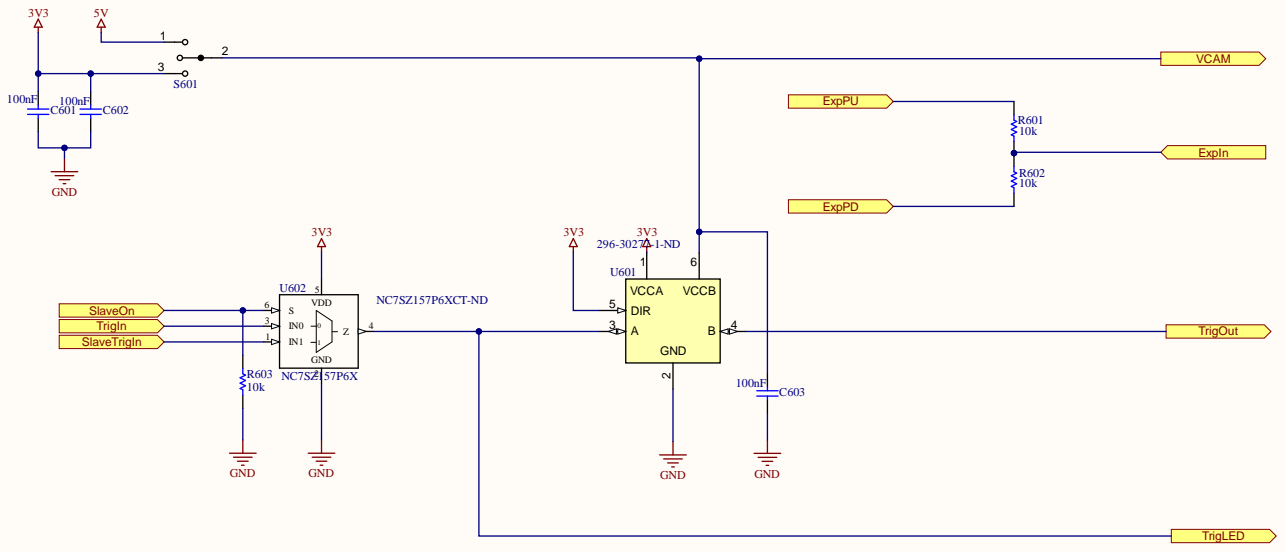
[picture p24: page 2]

VCCA VCCB

S 6 VDD GND

GND

Cannot open file C:\Users\michari | ETH Zürich, Leonhardstrasse 21, 8092 Zürich

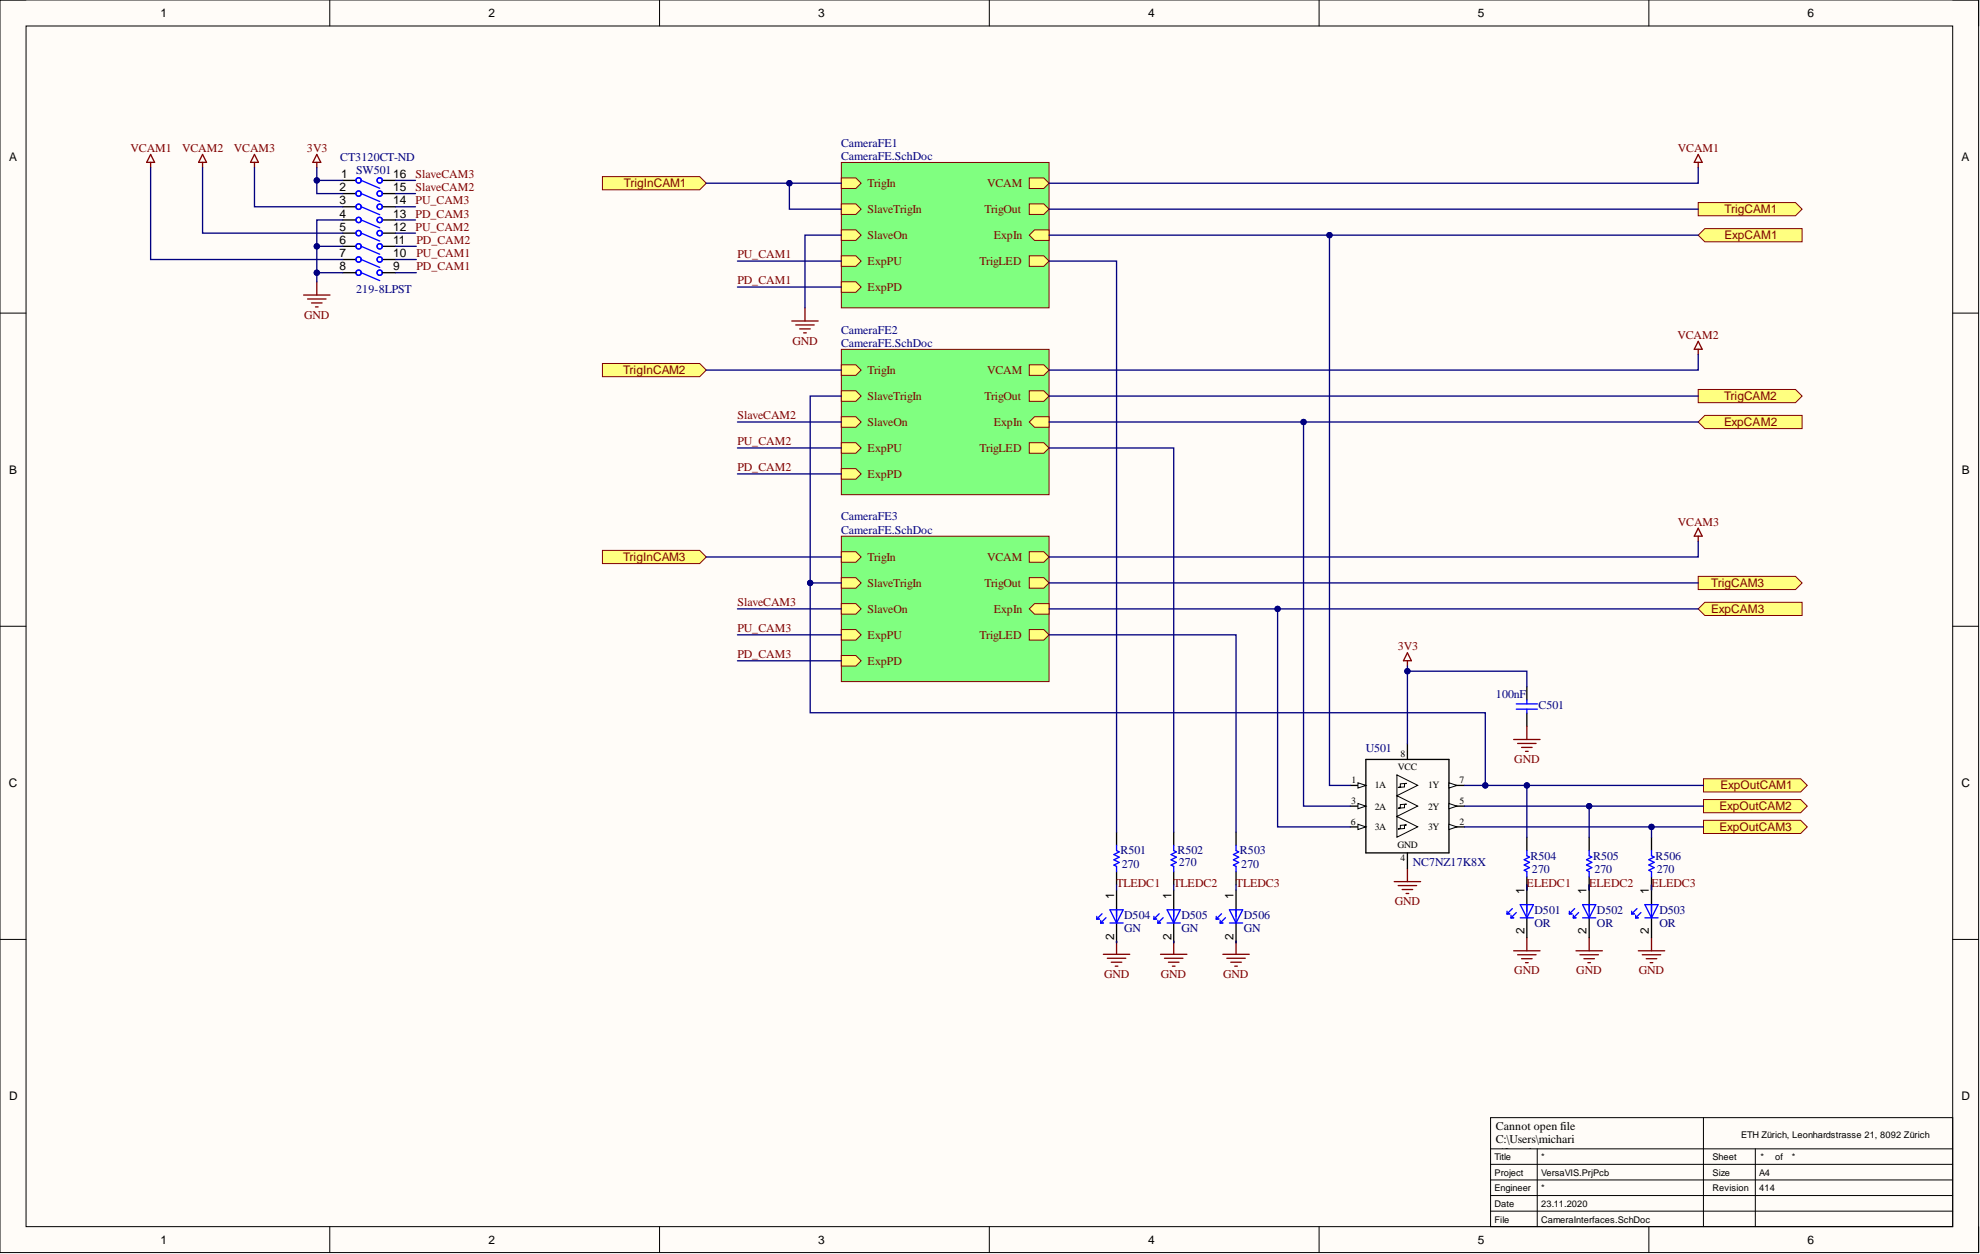
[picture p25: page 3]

ETH Zürich, Leonhardstrasse 21, 8092 Zürich

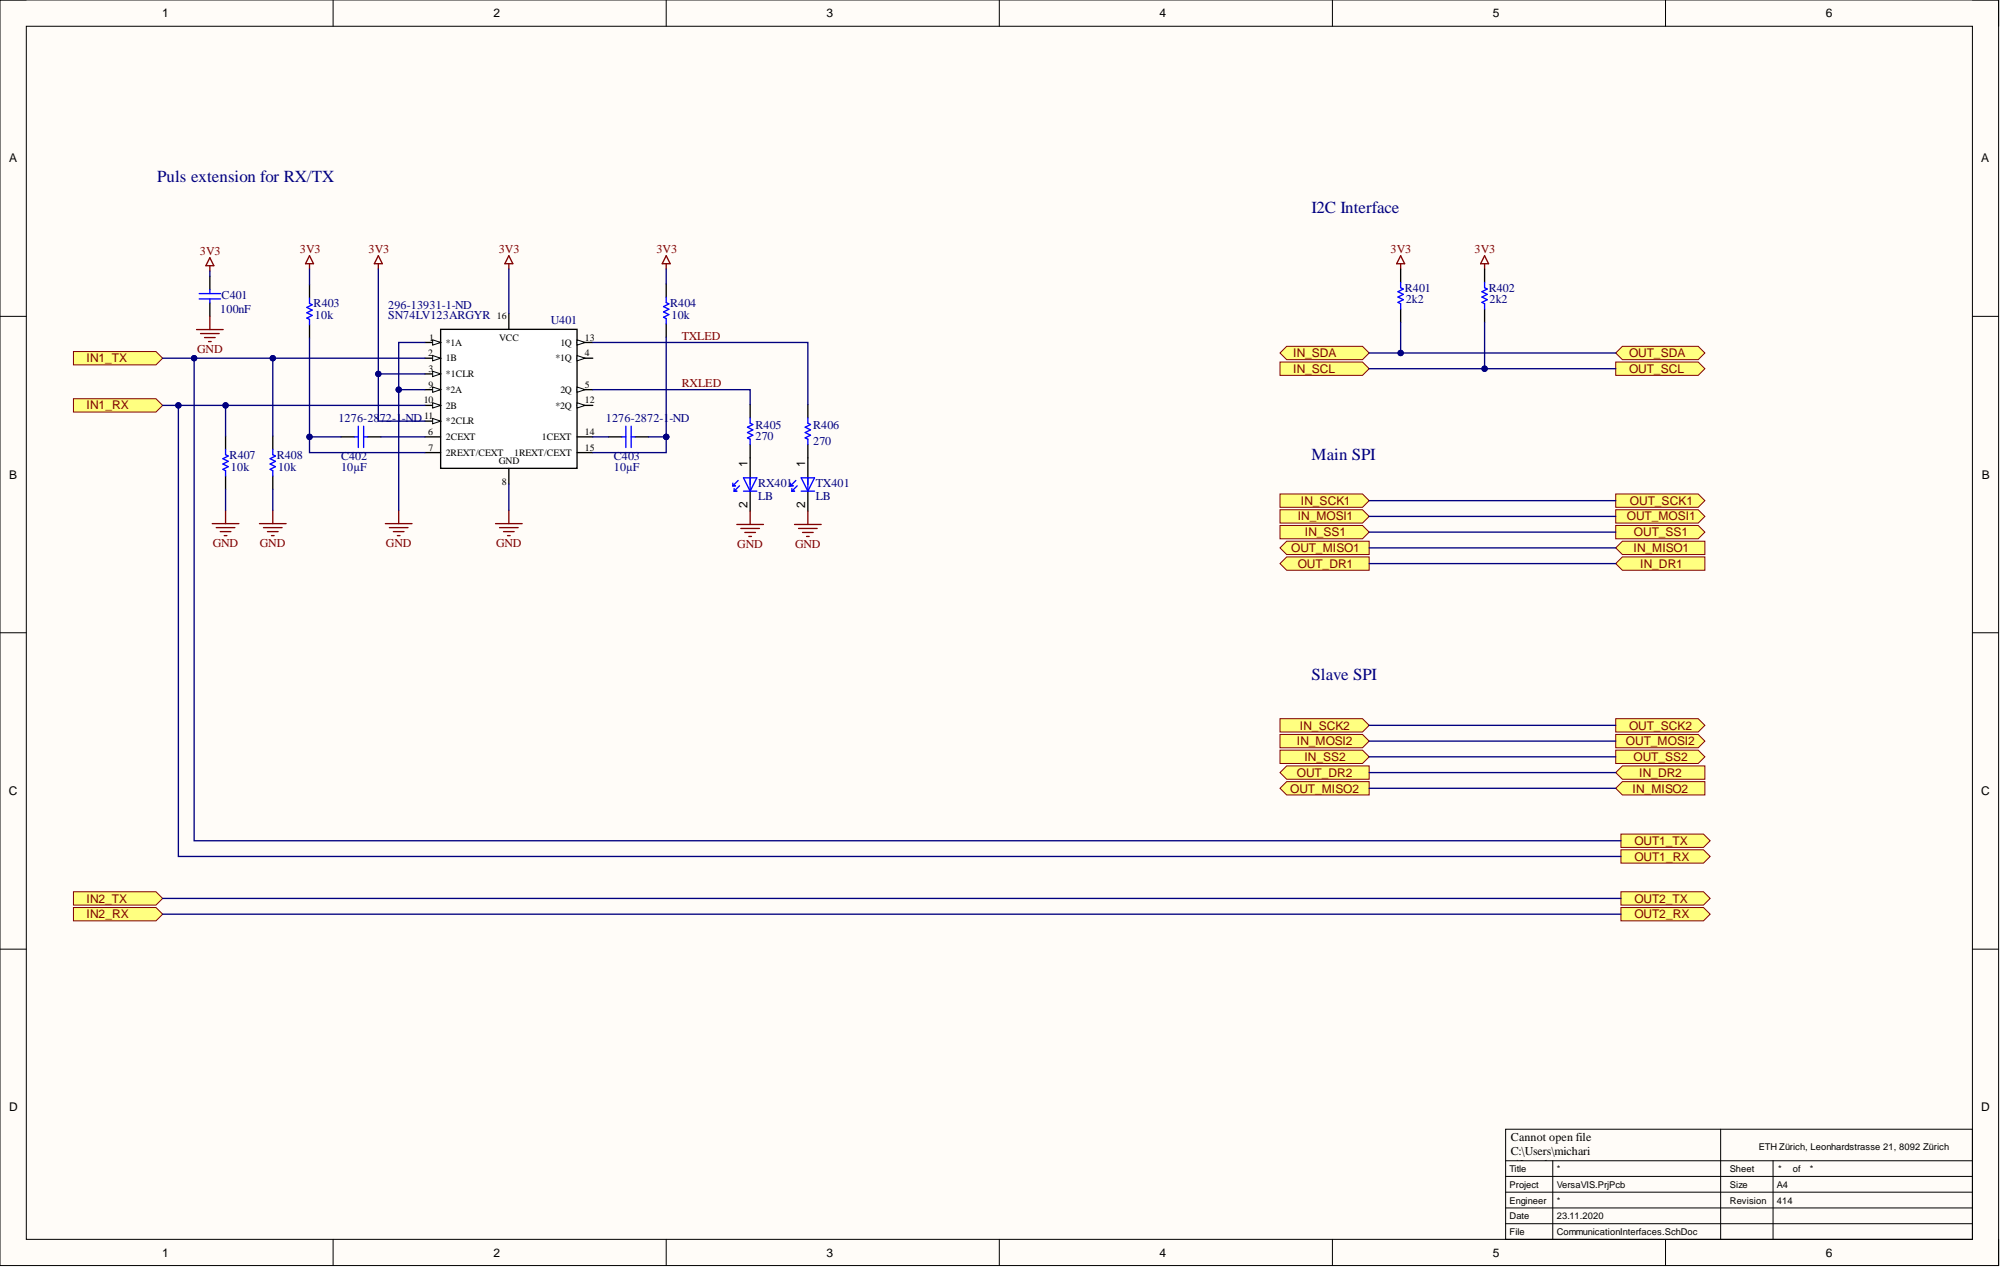
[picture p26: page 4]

Puls extension for RX/TX

*2A 9
2B 10 *2CLR 11

ETH Zürich, Leonhardstrasse 21, 8092 Zürich

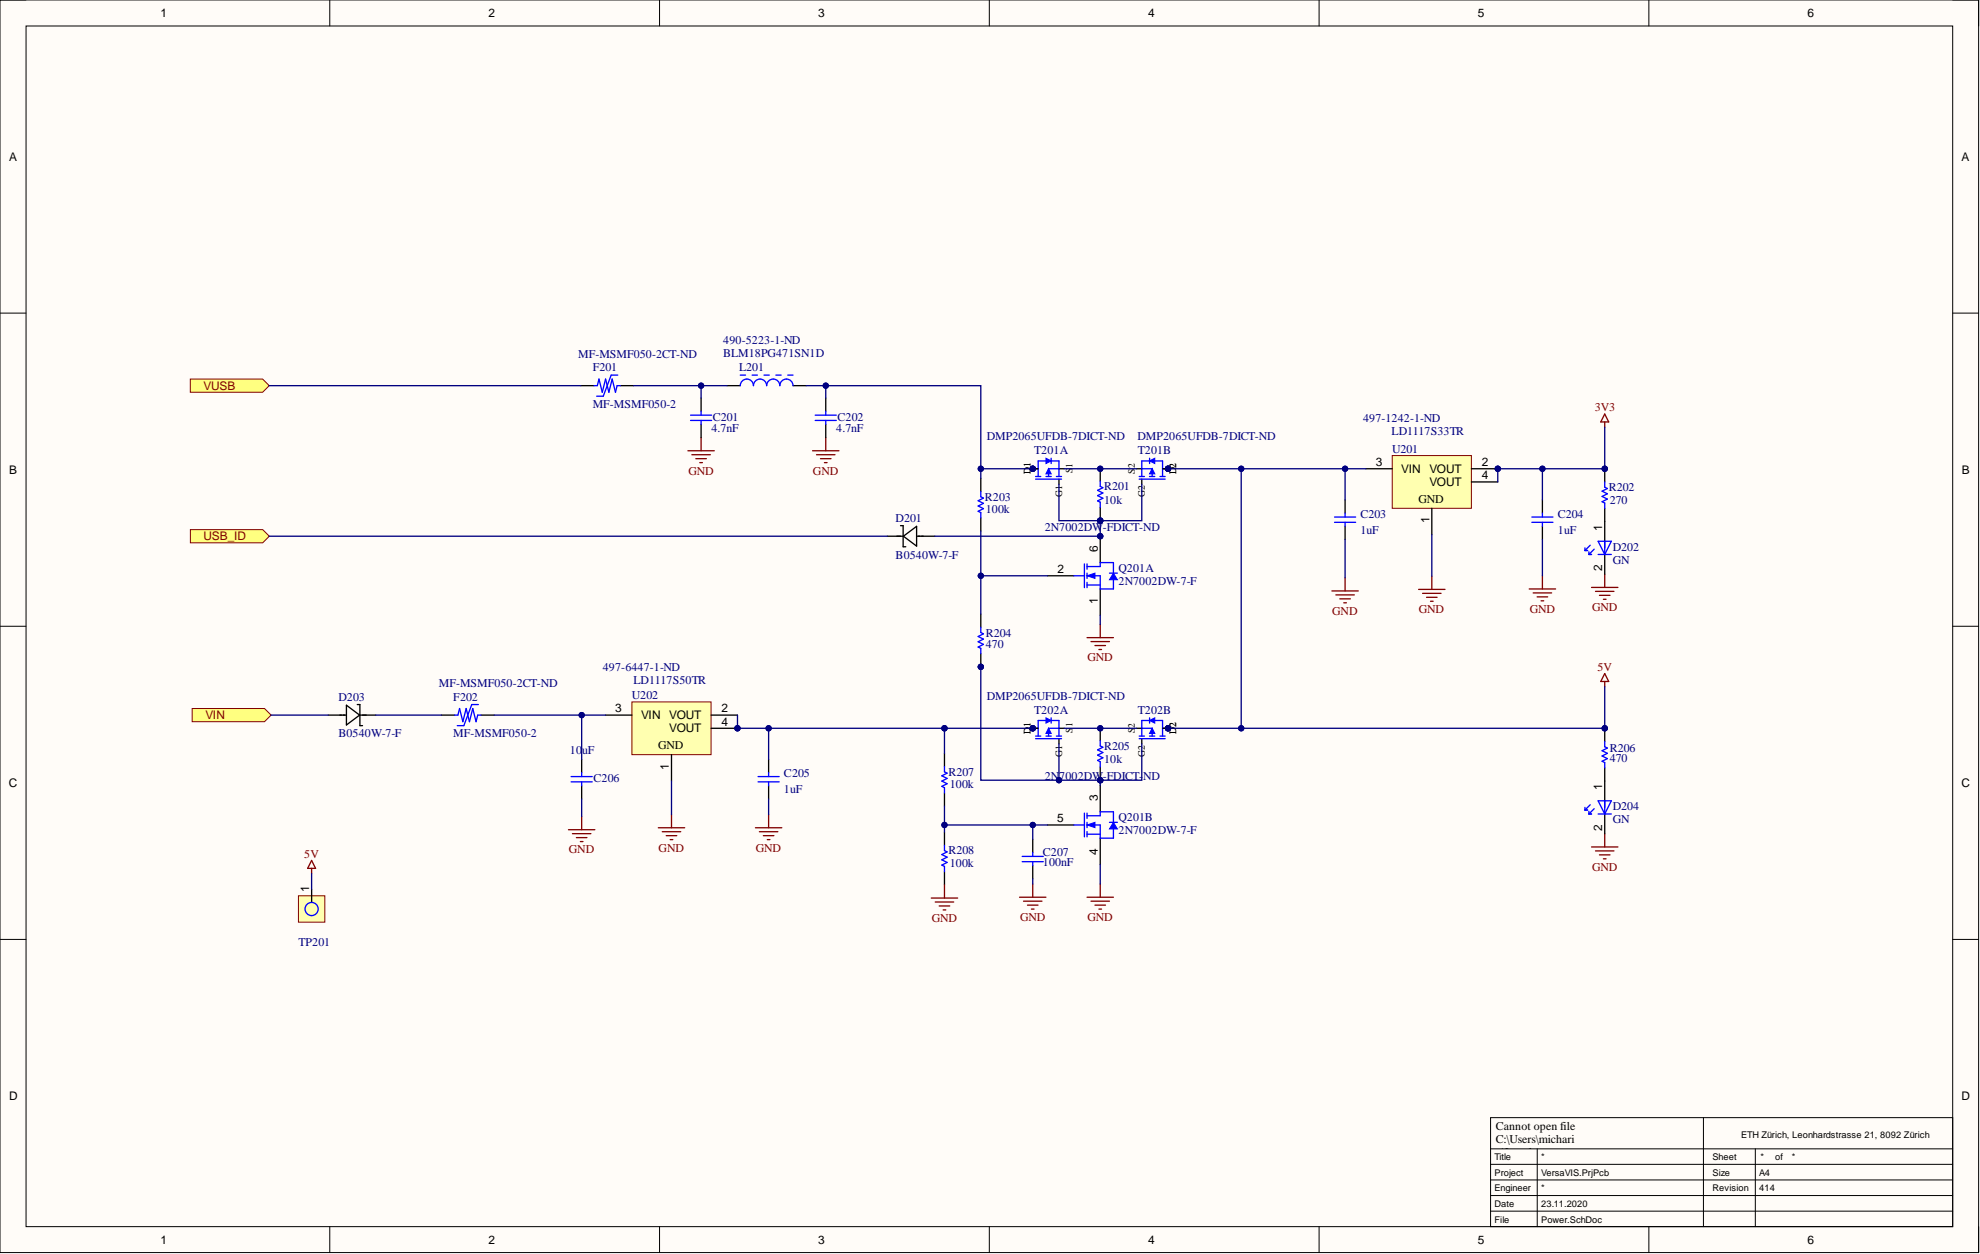
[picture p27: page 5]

ETH Zürich, Leonhardstrasse 21, 8092 Zürich

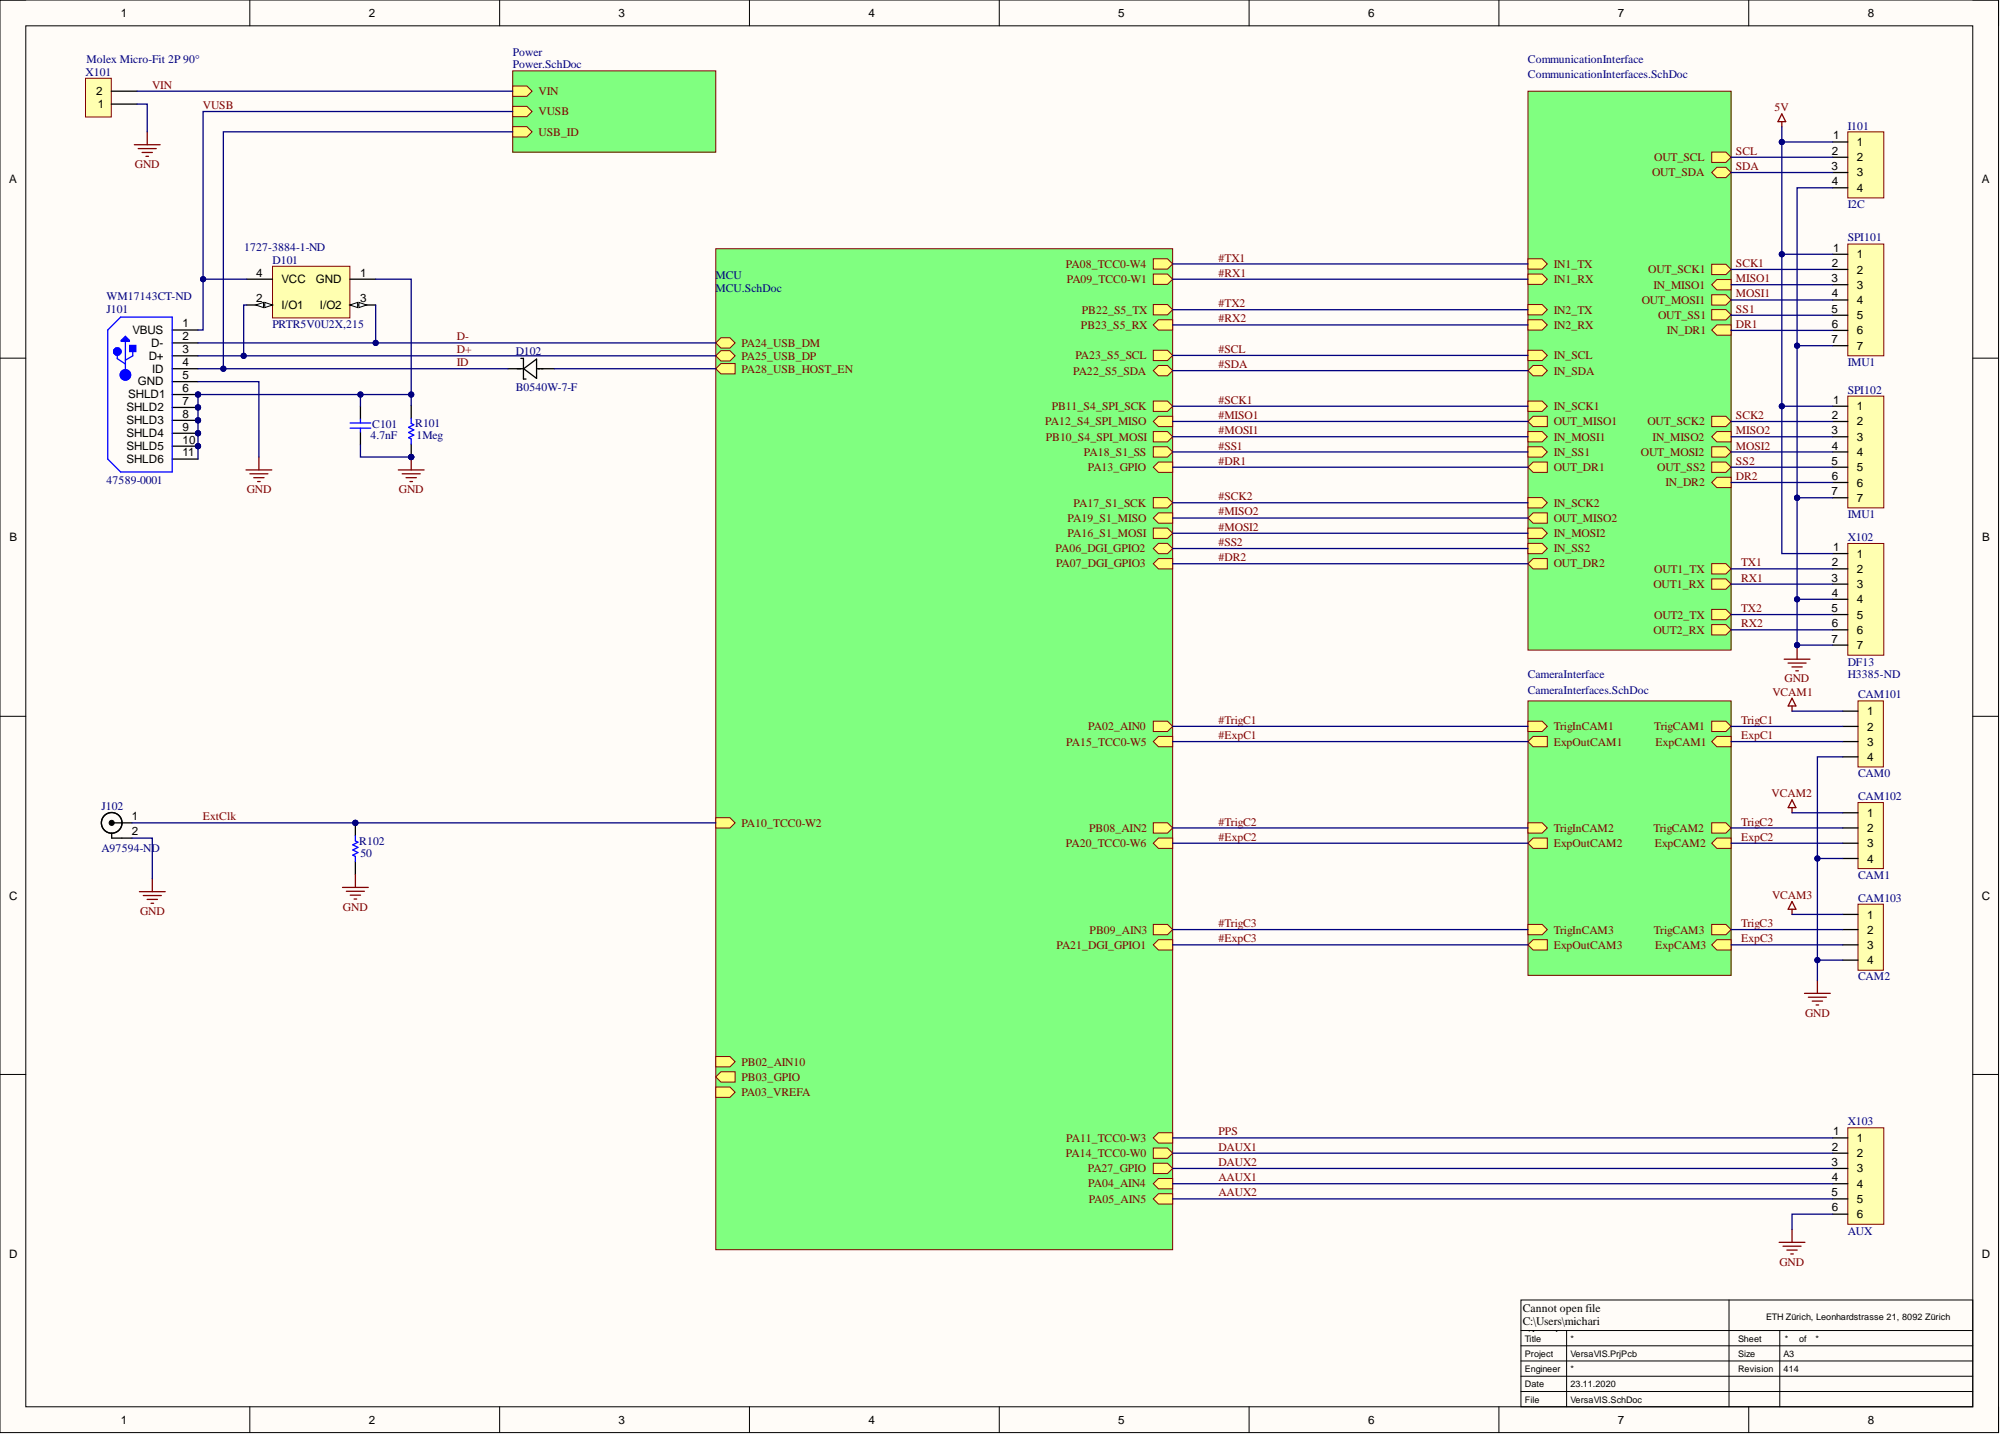
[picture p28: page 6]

SD A | | 3

3 | IDD+ | D 1 0 2
4 | | | #SD A
5 | | | #SCK 1

# DR1 | SS2 DR2 | 5
#SCK 2 | | 6

RX 1 | 3
T X 2 | 4

# Tri gC3 | Tri gC3
# E x p C 3 | E x p C 3

Can n o t o pen fi le C: \U sers \michari | ET H Z üri c h, L e o n h ard stra s s e 2 1, 8 2 Z üri c h

Titl e | *Vers | Sh e e t | o f
Pro j e c t | a VIS.PrjPc b | Si ze

En g i n e e r | | Re v i s i o n
Da te | 3.1 1.2

Fi l e | Vers a VIS.Sc hDo c

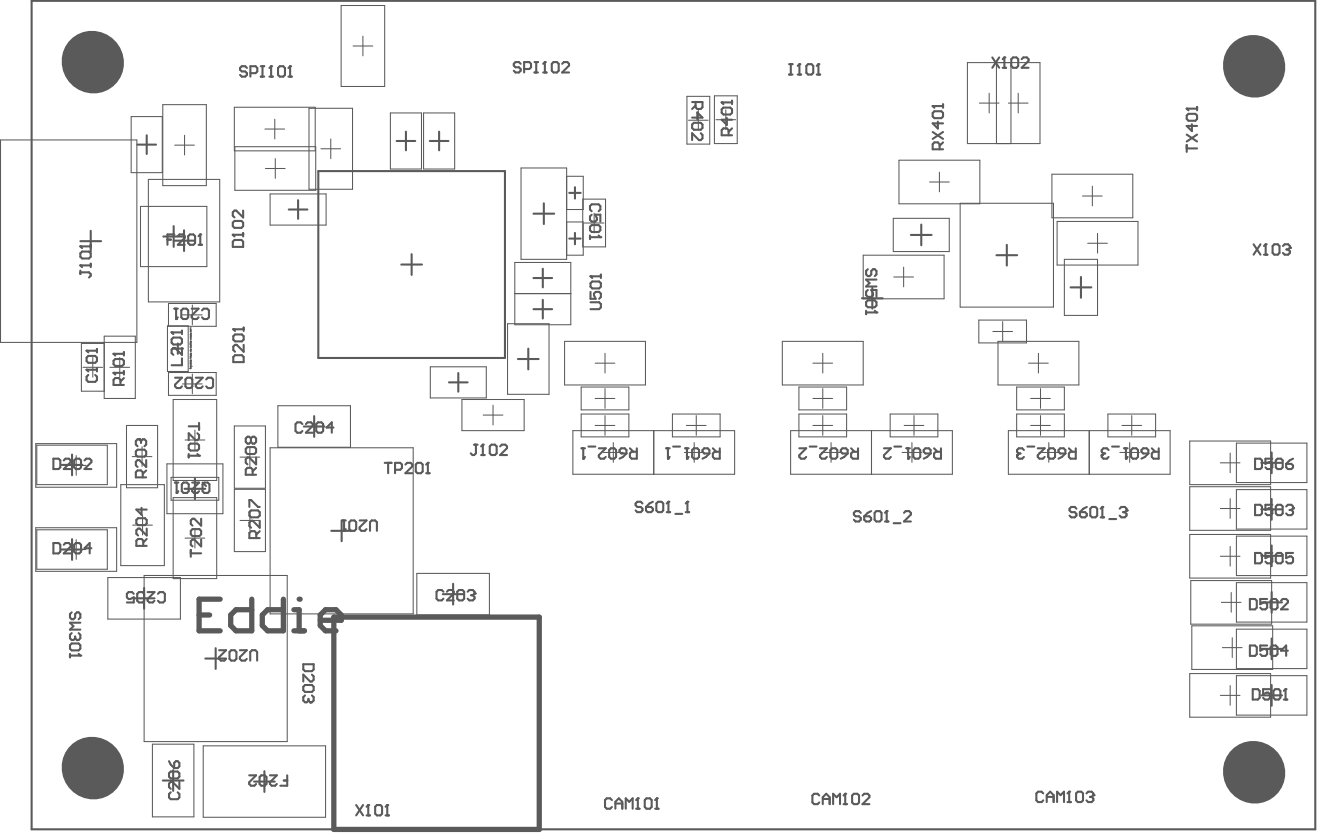
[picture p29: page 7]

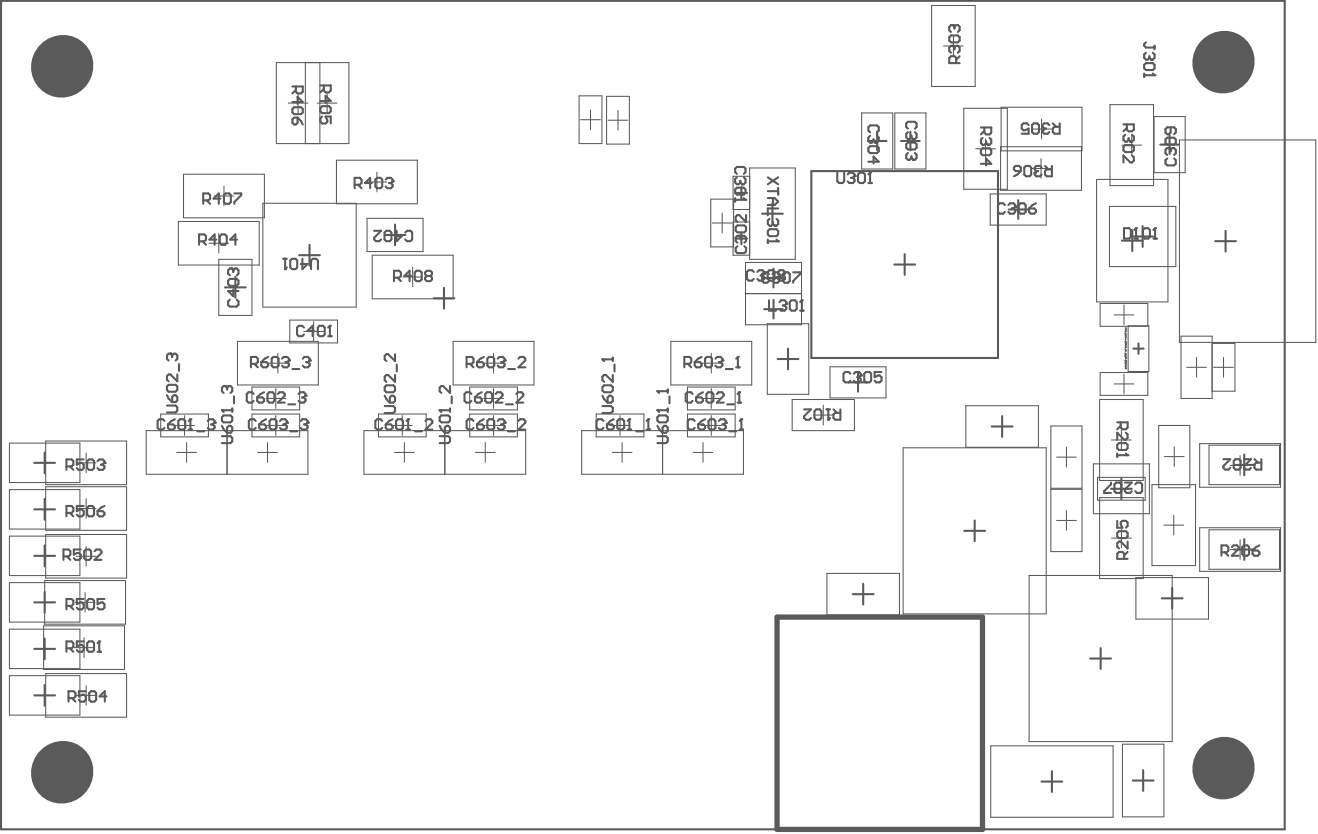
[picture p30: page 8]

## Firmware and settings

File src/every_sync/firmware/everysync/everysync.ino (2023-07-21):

// Import all settings for the chosen sensor configuration.
#include "every_sync_configuration.h"

#include <math.h>
#include <ros.h>
#include <std_msgs/UInt8.h>

#include "Arduino.h"

#ifdef USE_ADIS16445
#include <ADIS16445.h>
#elif defined(USE_ADIS16448AMLZ)
#include <ADIS16448AMLZ.h>
#elif defined(USE_ADIS16448BMLZ)
#include <ADIS16448BMLZ.h>
#elif defined(USE_ADIS16460)
#include <ADIS16460.h>
#elif defined(USE_VN100)
#include <VN100.h>
#endif
#include <Camera.h>
#include <Timer.h>
#include <helper.h>
// added 2023.5.1 by Kangkang
#include <Lidar.h>
#include <TriggerableIMU.h>
#include <GNSS.h>

// pps_time_test
#include <ros/time.h>
#include <tf/transform_broadcaster.h>
geometry_msgs::TransformStamped t;
tf::TransformBroadcaster broadcaster;
// Added for pps


static void resetCb(const std_msgs::Bool & /*msg*/) { NVIC_SystemReset(); }

#ifdef ILLUMINATION_MODULE
static void pwmCb(const std_msgs::UInt8 &msg) {
  analogWrite(ILLUMINATION_PWM_PIN, msg.data);
}
#endif


/* ----- ROS ----- */
ros::NodeHandle nh;
ros::Subscriber<std_msgs::Bool> reset_sub("/realvis/reset", &resetCb);
#ifdef ILLUMINATION_MODULE
ros::Subscriber<std_msgs::UInt8> pwm_sub("/realvis/illumination_pwm", &pwmCb);
#endif

/* ----- Timers ----- */
// In the current setup: TC5 -> IMU, TCC0 -> cam0, TCC1 -> cam1, TC3 -> cam2
// (TCC2 is used for pwm on pin 11).
// Be careful, there is NO bookkeeping whether the timer is already used or
// not. Only use a timer once, otherwise there will be unexpected behavior.

// Timer timer_cam0 = Timer((Tcc *)TCC0);
// Timer timer_imu = Timer((TcCount16 *)TC4);
Timer timer_trig_imu = Timer((Tcc *)TCC0);
Timer timer_cam1 = Timer((Tcc *)TCC1);
Timer timer_cam2 = Timer((TcCount16 *)TC3);
Timer timer_lidar = Timer((TcCount16 *)TC5);
Timer timer_gnss = Timer((Tcc *)TCC2);


/* ----- IMU ----- */
#ifdef USE_ADIS16445
ADIS16445 imu(&nh, IMU_TOPIC, IMU_RATE, timer_imu, 10, 2, 9);
#elif defined(USE_ADIS16448AMLZ)
ADIS16448AMLZ imu(&nh, IMU_TOPIC, IMU_RATE, timer_imu, 10, 2, 9);
#elif defined(USE_ADIS16448BMLZ)
ADIS16448BMLZ imu(&nh, IMU_TOPIC, IMU_RATE, timer_imu, 10, 2, 9);
#elif defined(USE_ADIS16460)
ADIS16460 imu(&nh, IMU_TOPIC, IMU_RATE, timer_imu, 10, 2, 9);
#elif defined(USE_VN100)
VN100 imu(&nh, IMU_TOPIC, IMU_RATE, timer_imu);
#elif defined(USE_BMI_088)
Bmi088 imu(&nh, IMU_TOPIC, IMU_RATE, timer_imu,SPI,10,38);
#elif defined(USE_ICM_42688)
ICM42688 imu(&nh, IMU_TOPIC, IMU_RATE, timer_imu,SPI,10);
#endif

/* ----- Cameras ----- */
// Camera cam0(&nh, CAM0_TOPIC, CAM0_RATE, timer_cam0, CAM0_TYPE, CAM0_TRIGGER_PIN,
//             CAM0_EXPOSURE_PIN, false);
Camera cam1(&nh, CAM1_TOPIC, CAM1_RATE, timer_cam1, CAM1_TYPE, CAM1_TRIGGER_PIN,
            CAM1_EXPOSURE_PIN, false);
Camera cam2(&nh, CAM2_TOPIC, CAM2_RATE, timer_cam2, CAM2_TYPE, CAM2_TRIGGER_PIN,
            CAM2_EXPOSURE_PIN, false);

// Camera lidar_test(&nh, LIDAR_TOPIC, LIDAR_RATE, timer_lidar, LIDAR_TYPE, LIDAR_TRIGGER_PIN,
//             LIDAR_EXPOSURE_PIN, false);

TriggerableIMU trig_imu(&nh, TRIG_IMU_TOPIC, TRIG_IMU_RATE, timer_trig_imu, TRIG_IMU_TYPE, TRIG_IMU_TRIGGER_PIN,
            TRIG_IMU_EXPOSURE_PIN, false);

Lidar lidar(&nh, LIDAR_TOPIC, LIDAR_RATE, timer_lidar, LIDAR_TYPE, LIDAR_TRIGGER_PIN,
            LIDAR_EXPOSURE_PIN, false);

GNSS gnss(&nh, EXTCLK_TOPIC, EXTCLK_RATE, timer_gnss, TRIG_IMU_TYPE, EXTCLK_NMEA_PIN,
            EXTCLK_PPS_PIN, false);


void setup() {
  DEBUG_INIT(115200);

/* ----- Define pins and initialize. ----- */
#ifdef ADD_TRIGGERS
  pinMode(ADDITIONAL_TEST_PIN, OUTPUT);
  digitalWrite(ADDITIONAL_TEST_PIN, LOW);
#endif

#ifdef ILLUMINATION_MODULE
  pinMode(ILLUMINATION_PWM_PIN, OUTPUT);
  pinMode(ILLUMINATION_PIN, OUTPUT);
  analogWrite(ILLUMINATION_PWM_PIN, 0);
  digitalWrite(ILLUMINATION_PIN, LOW);
#endif

  // delay(1000);

/* ----- ROS ----- */
#ifndef DEBUG
  nh.getHardware()->setBaud(250000);
  nh.initNode();
  nh.subscribe(reset_sub);

  // pps_time_test
  // broadcaster.init(nh);

#ifdef ILLUMINATION_MODULE
  nh.subscribe(pwm_sub);
#endif
#else
  while (!SerialUSB) {
    ; // wait for serial port to connect. Needed for native USB port only
  }
#endif

  DEBUG_PRINTLN(F("Main: Start setup."));

  // imu.setup();
  // cam0.setup();
  cam1.setup();
  cam2.setup();

  trig_imu.setup();

  lidar.setup();

  gnss.setup();

  /* ----- Initialize all connected cameras. ----- */
  // while (!cam0.isInitialized() || !cam1.isInitialized() ||
  //        !cam2.isInitialized() || !lidar.isInitialized()) {
  while (!trig_imu.isInitialized() || !cam1.isInitialized() ||
         !cam2.isInitialized() || !lidar.isInitialized()) {
    DEBUG_PRINTLN(F("Main: Initializing."));
    trig_imu.initialize();
    cam1.initialize();
    cam2.initialize();

    lidar.initialize();

    gnss.initialize();

#ifndef DEBUG
    nh.spinOnce();
#endif
    delay(1000);
  }

  /* -----  Declare timers ----- */
  // Enable TCC0 and TCC1 timers.
  REG_GCLK_CLKCTRL = static_cast<uint16_t>(
      GCLK_CLKCTRL_CLKEN | GCLK_CLKCTRL_GEN_GCLK0 | GCLK_CLKCTRL_ID_TCC0_TCC1);
  while (GCLK->STATUS.bit.SYNCBUSY == 1) {
    ; // wait for sync
  }
  // Enable TCC2 (not used) and TC3 timers.
  REG_GCLK_CLKCTRL = static_cast<uint16_t>(
      GCLK_CLKCTRL_CLKEN | GCLK_CLKCTRL_GEN_GCLK0 | GCLK_CLKCTRL_ID_TCC2_TC3);
  while (GCLK->STATUS.bit.SYNCBUSY == 1) {
    ; // wait for sync
  }

  // Enable TC4 (not used) and TC5 timers.
  REG_GCLK_CLKCTRL = static_cast<uint16_t>(
      GCLK_CLKCTRL_CLKEN | GCLK_CLKCTRL_GEN_GCLK0 | GCLK_CLKCTRL_ID_TC4_TC5);
  while (GCLK->STATUS.bit.SYNCBUSY == 1) {
    ; // wait for sync
  }

  // enable InterruptVector.
  NVIC_EnableIRQ(TCC0_IRQn);
  NVIC_EnableIRQ(TCC1_IRQn);
  
  NVIC_EnableIRQ(TC3_IRQn);
  NVIC_EnableIRQ(TC5_IRQn);

  // NVIC_EnableIRQ(TCC2_IRQn);

  // imu.begin();
  trig_imu.begin();
  cam1.begin();
  cam2.begin();

  lidar.begin();

  gnss.begin();

  /* ----- Interrupt for measuring the exposure time. ----- */
  noInterrupts(); // Disable interrupts to configure them --> delay()'s
  // currently not working!

  DEBUG_PRINTLN(F("Main: Attach interrupts."));
  // attachInterrupt(digitalPinToInterrupt(trig_imu.exposurePin()), exposureEnd0,
  //                 FALLING);
  attachInterrupt(digitalPinToInterrupt(trig_imu.exposurePin()), external_clockGet,
                  RISING);

  attachInterrupt(digitalPinToInterrupt(cam1.exposurePin()), exposureEnd1,
                  FALLING);
  attachInterrupt(digitalPinToInterrupt(cam2.exposurePin()), exposureEnd2,
                  FALLING);

  attachInterrupt(digitalPinToInterrupt(gnss.exposurePin()), external_clockGet,
                  RISING);
  // 为啥不好使。。。

  // DEBUG_PRINTLN(digitalPinToInterrupt(trig_imu.exposurePin()));
  // DEBUG_PRINTLN(digitalPinToInterrupt(cam1.exposurePin()));
  // DEBUG_PRINTLN(digitalPinToInterrupt(cam2.exposurePin()));
  // DEBUG_PRINTLN(digitalPinToInterrupt(gnss.exposurePin()));

  interrupts();

  DEBUG_PRINTLN(F("Main: Setup done."));
}

void loop() {
  trig_imu.publish();
  cam1.publish();
  cam2.publish();

  // imu.publish();

  lidar.publish();
  gnss.publish();

  delayMicroseconds(500);
  //For Transform Buffer


#ifndef DEBUG
  nh.spinOnce();
#endif
}

void TCC0_Handler() { // Called by cam0_timer for camera 0 trigger.
  trig_imu.triggerMeasurement();
    // trig_imu.publish();
}

void TCC1_Handler() { // Called by cam1_timer for camera 1 trigger.
  cam1.triggerMeasurement();
    // cam1.publish();
}

void TC3_Handler() { // Called by imu_timer for imu trigger.
  cam2.triggerMeasurement();
    // cam2.publish();
}

void TC5_Handler() { // Create a series of Pulse for lidar with timestamps
  // lidar.triggerMeasurement();
  // lidar.pps_send_utc_time();
  lidar.pps_send_utc_time_from_100hz();
}

// void TCC2_Handler() {

// }

void exposureEnd0() {
  trig_imu.exposureEnd();
#ifdef ILLUMINATION_MODULE
  // Deactivate the LEDs with the last camera.
  if (!cam1.isExposing() && !cam2.isExposing()) {
    digitalWrite(ILLUMINATION_PIN, LOW);
  }
#endif
}

void exposureEnd1() {
  cam1.exposureEnd();
#ifdef ILLUMINATION_MODULE
  // Deactivate the LEDs with the last camera.
  if (!cam0.isExposing() && !cam2.isExposing()) {
    digitalWrite(ILLUMINATION_PIN, LOW);
  }
#endif
}

void exposureEnd2() {
  cam2.exposureEnd();
#ifdef ILLUMINATION_MODULE
  // Deactivate the LEDs with the last camera.
  if (!cam0.isExposing() && !cam1.isExposing()) {
    digitalWrite(ILLUMINATION_PIN, LOW);
  }
#endif
}

void external_clockGet()
{
  gnss.get_ext_clk_time();
}

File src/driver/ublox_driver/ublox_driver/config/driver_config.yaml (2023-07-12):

%YAML:1.0

# input options
online: 1           # input from serial port(1) or file(0)
## if `online == 1` then following options may be set
input_serial_port: "/dev/ttyACM1"
#input_serial_port: "/dev/ubloxF9P"
serial_baud_rate: 921600
input_rtcm: 0       # whether input RTCM data to receiver for RTK solution
rtcm_tcp_port: 3503
config_receiver_at_start: 0     # whether to config receiver during booting, ** NOT SUPPORT YET **
receiver_config_filepath: "~/catkin_ws/src/ublox_driver/config/ublox_rcv_config.yaml"
## if `online == 0` then following options may be set, `serial_baud_rate` is used for speed control
ubx_filepath: "~/tmp/ublox_driver_test/2020_11_30_7_14_33.ubx"
rtk_correction_ecef:      # apply RTK correction in case of the position of base station reported in RTCM is biased
    rows: 3
    cols: 1
    dt: d
    data: [ 0, 0, 0 ]

# output options
to_ros: 1           # publish as ros topic
to_file: 0          # dump data to file
dump_dir: "~/tmp/ublox_driver_test/"      # dump data to this directory, if applicable
to_serial: 0        # output data to serial port, for debugging purpose
output_serial_port: "/dev/ttyACM1"                  # dump data to this serial port, if applicable
#output_serial_port: "/dev/ubloxF9P"                  # dump data to this serial port, if applicable

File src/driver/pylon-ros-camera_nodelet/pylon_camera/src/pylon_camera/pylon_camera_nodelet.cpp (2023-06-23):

#include <ros/ros.h>
#include <boost/thread.hpp>
#include <pylon_camera/pylon_camera_node.h>
#include <image_numbered_msgs/ImageNumbered.h>

//* 必要头文件
#include <pluginlib/class_list_macros.h>
#include <nodelet/nodelet.h>

// uint64 seq_num=0;
// ros::Publisher ImgNumbered_pub_;
// image_numbered_msgs::ImageNumbered IN_msg;

namespace pylon_camera_ns
{
    class Nodelet : public nodelet::Nodelet
    {
        public:
            virtual void onInit()
            {

                boost::shared_ptr<boost::thread> spinThread_;
                
                // pylon_camera::PylonCameraNode pylon_camera_node;
                pylon_camera::PylonCameraNode pylon_camera_node(getPrivateNodeHandle());
                
                // ros::NodeHandle basler_camera;
                // ImgNumbered_pub_ = basler_camera.advertise<image_numbered_msgs::ImageNumbered>("/basler_camera_node/img_numbered", 1000);

                ros::Rate r(pylon_camera_node.frameRate());
                
                ROS_INFO_STREAM("Start image grabbing if node connects to topic with "
                    << "a frame_rate of: " << pylon_camera_node.frameRate() << " Hz");

                // spinThread_ = boost::shared_ptr<boost::thread>(new boost::thread(boost::bind(&pylon_camera_ns::spin, this)));
                // Main thread and brightness-service thread
                
                // boost::thread th(boost::bind(&ros::spin));

                while ( ros::ok() )
                {
                    pylon_camera_node.spin();
                    
                    // IN_msg.image = pylon_camera_node.img_raw_msg_;
                    // IN_msg.number = seq_num;
                    // IN_msg.exposure = 0;S
                    // new_pub_.publish(IN_msg);
                    // seq_num ++;
                    r.sleep();
                }

                ROS_INFO("Terminate PylonCameraNode");
                // return EXIT_SUCCESS;
            }



            // void PylonCameraNodelet::spin()
            // {
            //     while (true)
            //     {
            //         ros::Rate r(pylon_camera_node.frameRate());
            //         while (ros::ok() )
            //         {
            //             pylon_camera_node.spin();
            //             IN_msg.image = pylon_camera_node.img_raw_msg_;
            //             IN_msg.number = seq_num;
            //             IN_msg.exposure = 0;
            //             new_pub_.publish(IN_msg);
            //             // seq_num ++;

            //             r.sleep();
            //         }
            //     }
            // }
    };
    PLUGINLIB_EXPORT_CLASS(pylon_camera_ns::Nodelet, nodelet::Nodelet)
}

// int main(int argc, char **argv)
// {
//     ros::init(argc, argv, "pylon_camera_node");
//     pylon_camera::PylonCameraNode pylon_camera_node;
    
//     //新增可发布image_numbered话题 
//     ros::init(argc, argv, "basler_camera");
//     ros::NodeHandle basler_camera;
//     ros::Publisher new_pub_ = basler_camera.advertise<image_numbered_msgs::ImageNumbered>("/basler_camera_node/img_numbered", 1000);
    

//     ros::Rate r(pylon_camera_node.frameRate());

//     ROS_INFO_STREAM("Start image grabbing if node connects to topic with "
//         << "a frame_rate of: " << pylon_camera_node.frameRate() << " Hz");

//     // Main thread and brightness-service thread
//     boost::thread th(boost::bind(&ros::spin));

//     while ( ros::ok() )
//     {
//         pylon_camera_node.spin();
        
//         image_numbered_msgs::ImageNumbered IN_msg;
        
//         IN_msg.image = pylon_camera_node.img_raw_msg_;
//         IN_msg.number = seq_num;
//         IN_msg.exposure = 0;
//         new_pub_.publish(IN_msg);
//         // seq_num ++;

//         r.sleep();
//     }

//     ROS_INFO("Terminate PylonCameraNode");
//     return EXIT_SUCCESS;
// }

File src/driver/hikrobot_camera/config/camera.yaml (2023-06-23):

# true 1 和 false 0 
# width: 752             #图像宽度
# height: 480            #图像高度
# Offset_x: 584             #X方向偏置
# Offset_y: 360             #Y方向偏置

width: 1080             #图像宽度
height: 720            #图像高度
Offset_x: 420             #X方向偏置
Offset_y: 240             #Y方向偏置

# width: 1920             #图像宽度
# height: 1200            #图像高度
# Offset_x: 0             #X方向偏置
# Offset_y: 0             #Y方向偏置

FrameRateEnable: true   #使能 
FrameRate: 30           #帧率

ExposureTime: 19000     #曝光时间

GammaEnable: true
Gamma: 0.7              #伽马因子

GainAuto: 2             #亮度的固定增益

SaturationEnable: false
Saturation: 128          #饱和度

TriggerMode: 0
TriggerSource: 0    #线路0
LineSelector: 1     #线路1
LineMode: 8         #频闪输出
LineSource: 0       #曝光开始输出
StrobeEnable: 1     #输出使能

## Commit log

2025-01-12 20250112 : PCB & Example Handheld Release
    Update EverySync_PCB with both LCEDA and AltiumDesigner Version. The handheld example is also released.
    [0531_battery_cont.SLDPRT, 0531_pc_content.SLDPRT, 1_01 MCU.SchDoc.schdoc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]
2025-02-17 update driver link in README
2025-03-27 update PCB for LCEDA
2026-03-09 2026.3.9 项目可直接在立创开源广场查看
